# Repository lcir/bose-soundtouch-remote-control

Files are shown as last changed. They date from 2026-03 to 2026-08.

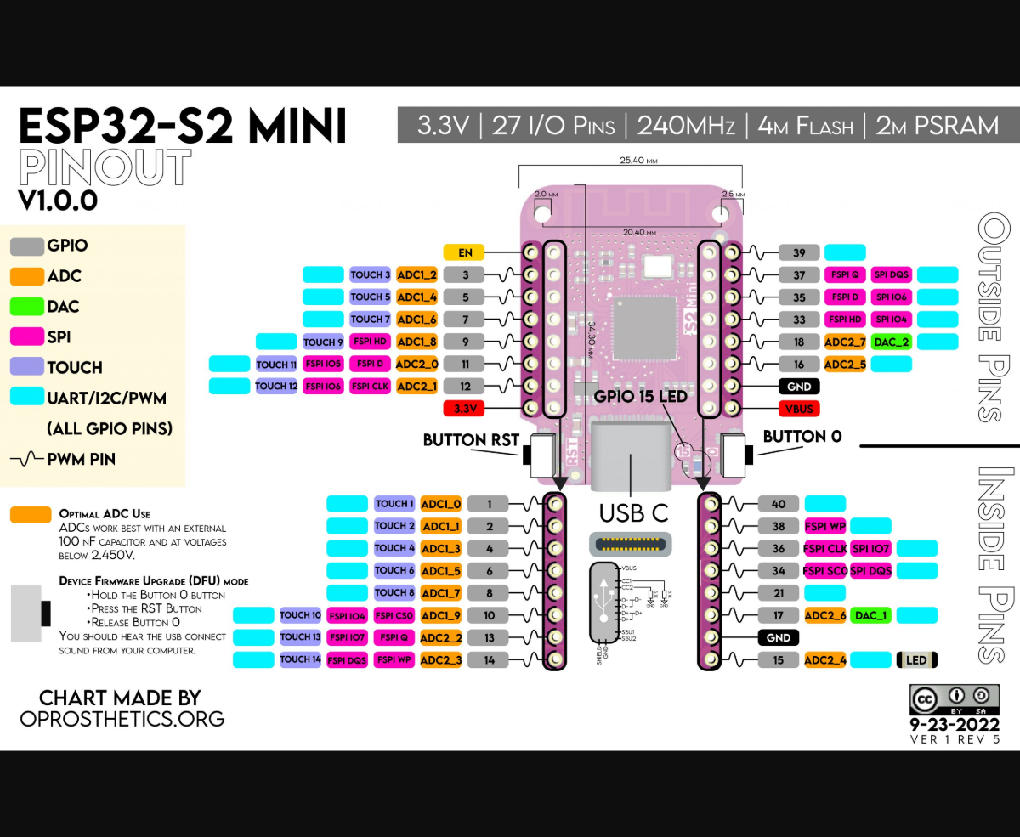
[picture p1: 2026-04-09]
docs/assets/wemos-s2-mini-pinout-base.png

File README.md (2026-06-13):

# Bose SoundTouch SA-5 ESP32 Remote

ESP32 firmware for a dedicated Bose SoundTouch SA-5 wall/desk controller.

Detailed project documentation is in [docs/README.md](/Users/peny/Development/Projects/boser-remote-control/docs/README.md).

Mechanical enclosure CAD is in [cad/bose_remote_enclosure.scad](/Users/peny/Development/Projects/boser-remote-control/cad/bose_remote_enclosure.scad).

The project now defaults to `LOLIN/Wemos S2 Mini` for prototyping.

## Features

- Captive portal setup for Wi-Fi and Bose hostname/IP
- Bose SoundTouch local control over HTTP (`8090`) and WebSocket (`8080`)
- Built-in LAN web UI for phone/browser control
- Rotary encoder volume control with request coalescing
- Encoder push-button driven OLED menu for `Volume`, `Source`, and `Power`
- Single status LED: `on = Bose powered on`, `off = standby/unavailable`
- `128x64` OLED status UI (`SSD1306` over `I2C`)
- Over-the-air (OTA) self-update from GitHub Releases via the web UI

## Default wiring

Current defaults are for `LOLIN/Wemos S2 Mini` and a generic `0.96" 128x64 I2C OLED`.
Change these in `include/PinConfig.h` if your hardware differs.

- `GPIO33` `SDA`
- `GPIO35` `SCL`
- `GPIO7` encoder `A`
- `GPIO9` encoder `B`
- `GPIO11` encoder switch / setup hold button
- `GPIO18` status LED

Buttons are assumed `active low` with `INPUT_PULLUP`.

## Setup flow

1. Flash firmware.
2. On first boot, connect to Wi-Fi `BoseRemote-xxxx`.
3. Open `http://192.168.4.1`.
4. Enter home Wi-Fi credentials and Bose `hostname` or `IP`.
5. Device reboots into normal station mode.

Holding the encoder button during boot for roughly `1.5 s` forces setup mode again.

## Encoder Control

- rotate in idle mode: change volume
- short press: open the OLED menu
- rotate in the menu: choose `Volume`, `Source`, or `Power`
- short press on `Source` or `Power`: open a submenu
- confirm a submenu choice with another short press
- after confirmation, the menu closes and the controller returns to idle volume mode

## LAN Web UI

In normal station mode, the ESP32 also serves a local control page on its own IP address.
Open `http://<esp32-ip>/` in a browser on the same network to:

- change volume
- switch to the next logical source, including `AUX`, `Bluetooth` and grouped `Online`
- directly select the grouped sources exposed by the web UI
- send dynamic `Wake` / `Standby`
- view current Bose state
- check for and apply firmware updates (see below)

## Firmware updates (OTA)

The controller can update its own firmware over the air, pulling the build from
this repo's GitHub Releases — no USB cable needed after the first flash.

How it works:

1. Pushing a `vX.Y.Z` tag triggers the `Build Firmware` workflow, which compiles
   each board and publishes `firmware-<env>.bin` as assets on a GitHub Release.
2. The running firmware embeds its own version (`FIRMWARE_VERSION`, derived from
   the git tag at build time via `scripts/version.py`).
3. In the LAN web UI, the **Firmware** section calls the GitHub API for the
   latest release, compares the tag against the installed version, and offers
   **Update now** when a newer release exists.
4. The device downloads the asset matching its board (`firmware-<env>.bin`),
   flashes it to the inactive OTA slot, and reboots into the new image.

REST endpoints backing this: `GET /api/ota` (status), `POST /api/ota/check`,
`POST /api/ota/apply`.

Cutting a release:

```bash
git tag v0.1.0
git push origin v0.1.0
```

Notes:

- The 4 MB modules use the dual-app `default.csv` partition layout
  (`board_build.partitions`), giving two ~1.25 MB OTA slots. A failed download
  leaves the running image untouched.
- TLS to GitHub uses `setInsecure()` (no certificate pinning) to keep the image
  small; traffic still goes only to `api.github.com` / GitHub's asset CDN and
  only when an update is explicitly requested.

## Build

This repo is prepared for `PlatformIO`.

```bash
pio run
pio run -t upload
pio device monitor
```

The default environment is `lolin_s2_mini`. A compatibility target for generic classic ESP32 boards is still available via:

```bash
pio run -e esp32dev
```

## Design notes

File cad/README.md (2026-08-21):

# CAD návrh krabičky

Parametrický návrh původní svislé krabičky je v [bose_remote_enclosure.scad](/Users/peny/Development/Projects/boser-remote-control/cad/bose_remote_enclosure.scad).

Kompaktní landscape varianta s `OLED` a knobem vedle sebe je v [compact_landscape_enclosure.scad](compact_landscape_enclosure.scad).

## Kompaktní landscape varianta

Nová nízká varianta má vnější rozměry `88 x 34 x 38 mm`:

- `OLED` vlevo
- enkodér / knob vpravo
- bez samostatné stavové `LED`
- `LOLIN/Wemos S2 Mini` uložený naležato v levé spodní kapsě za `OLED`
- S2 Mini se zasouvá zezadu do bočních lišt, `USB-C` míří k zadnímu víku
- kolečko je panelový rotační enkodér: tělo enkodéru je uvnitř, hřídel jde otvorem ven a knob je zvenku
- zadní víko se `USB-C` výřezem, otevřeným spodním slotem pro kabel a ventilačními průřezy

Vygenerované STL díly:

- [compact-landscape-body.stl](compact-landscape-body.stl)
- [compact-landscape-rear-lid.stl](compact-landscape-rear-lid.stl)
- [compact-landscape-panel-layout.stl](compact-landscape-panel-layout.stl)

## Co model obsahuje

- `body`: hlavní díl krabičky s integrovaným čelním panelem, dnem, ložem pro `LOLIN/Wemos S2 Mini`, OLED standoffy a zadním otevřeným servisním prostorem
- `rear_lid`: zadní víko na `4x` šroubek s `USB-C` otvorem a otevřeným slotem pro vedení kabelu
- `panel_layout`: tenký kontrolní výřez rozložení čelního panelu
- `assembly`: vizuální sestava s referenčními bloky pro `OLED`, `S2 Mini`, enkodér a knob

## Výchozí mechanické předpoklady

Model je připravený pro:

- `LOLIN/Wemos S2 Mini`
- běžný `0.96" SSD1306 128x64 I2C OLED` modul
- enkodér s panelovým závitem a zadním modulem podobným `LA132020`

Původní svislý model používá stack `OLED`, enkodér, `LED`.
Kompaktní landscape model používá pouze `OLED` a enkodér vedle sebe.

Pokud se skutečné díly liší, uprav přímo horní parametry v `.scad`.

## Kritické rozměry k přeměření

Před prvním finálním tiskem přeměř:

- `oled_board`, `oled_hole_spacing`, `oled_window`
- `encoder_panel_hole_d` a zadní obrys encoder modulu
- `s2_board`, `usb_opening`, `usb_slot_center_z`

## Export

Pokud máš nainstalovaný `OpenSCAD`, typický export je:

```bash
openscad -D 'part="body"' -o body.stl cad/bose_remote_enclosure.scad
openscad -D 'part="rear_lid"' -o rear-lid.stl cad/bose_remote_enclosure.scad
openscad -D 'part="panel_layout"' -o panel-layout.stl cad/bose_remote_enclosure.scad
```

Export kompaktní landscape varianty:

```bash
openscad -D 'part="body"' -o cad/compact-landscape-body.stl cad/compact_landscape_enclosure.scad
openscad -D 'part="rear_lid"' -o cad/compact-landscape-rear-lid.stl cad/compact_landscape_enclosure.scad
openscad -D 'part="panel_layout"' -o cad/compact-landscape-panel-layout.stl cad/compact_landscape_enclosure.scad
```

## Doporučení pro tisk

- tisknout `body` čelním panelem na podložce; tím vznikne čistý pohledový čelní panel a zadní strana zůstane otevřená pro montáž
- tisknout `rear_lid` plochou stranou na podložce
- pro rychlé ověření rozložení prvků nejdřív vytisknout `panel_layout`
- tryska `0.4 mm`, vrstva `0.2 mm`, `3-4` perimetry
- materiál `PLA` pro rychlý prototyp, `PETG` pro trvalejší kus

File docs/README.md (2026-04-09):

# Dokumentace projektu

Tento adresář obsahuje technickou dokumentaci pro `ESP32` ovladač zesilovače `Bose SoundTouch SA-5`.

English version: [docs/en/README.md](/Users/peny/Development/Projects/boser-remote-control/docs/en/README.md)

## Obsah

- [Přehled projektu](/Users/peny/Development/Projects/boser-remote-control/docs/overview.md)
- [Firmware a provoz](/Users/peny/Development/Projects/boser-remote-control/docs/firmware.md)
- [Zapojení a spojení vodičů](/Users/peny/Development/Projects/boser-remote-control/docs/wiring.md)
- [Bill of Materials](/Users/peny/Development/Projects/boser-remote-control/docs/bom.md)
- [Návrh krabičky](/Users/peny/Development/Projects/boser-remote-control/docs/enclosure.md)

## Rychlá orientace

- `ESP32` komunikuje s `Bose SA-5` pouze přes `Wi‑Fi`.
- Na Bose se nepřipojuje žádný ovládací vodič, relé ani analogový potenciometr.
- Všechny fyzické ovládací prvky jsou připojené jen k `ESP32`.
- `ESP32` posílá do Bose lokální síťové příkazy přes `HTTP` a poslouchá změny přes `WebSocket`.
- V normálním režimu `ESP32` zároveň poskytuje lokální webové ovládání v LAN.
- Web aktuálně nabízí dynamické `Wake/Standby` a seskupené zdroje `AUX`, `Bluetooth`, `Online`.
- [wiring.md](/Users/peny/Development/Projects/boser-remote-control/docs/wiring.md) nově obsahuje i obrazek s projektovym pinoutem `LOLIN/Wemos S2 Mini` a napojenymi komponentami.

## Soubory v projektu

- Hlavní firmware: [main.cpp](/Users/peny/Development/Projects/boser-remote-control/src/main.cpp)
- Bose komunikace: [BoseClient.cpp](/Users/peny/Development/Projects/boser-remote-control/src/BoseClient.cpp)
- Setup portal: [CaptivePortal.cpp](/Users/peny/Development/Projects/boser-remote-control/src/CaptivePortal.cpp)
- LAN web UI: [ControlWebServer.cpp](/Users/peny/Development/Projects/boser-remote-control/src/ControlWebServer.cpp)
- Vstupy: [InputController.cpp](/Users/peny/Development/Projects/boser-remote-control/src/InputController.cpp)
- OLED UI: [UiRenderer.cpp](/Users/peny/Development/Projects/boser-remote-control/src/UiRenderer.cpp)
- Piny: [PinConfig.h](/Users/peny/Development/Projects/boser-remote-control/include/PinConfig.h)

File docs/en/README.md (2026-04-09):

# Project Documentation

This directory contains the English technical documentation for the `ESP32` controller for the `Bose SoundTouch SA-5` amplifier.

## Contents

- [Project Overview](/Users/peny/Development/Projects/boser-remote-control/docs/en/overview.md)
- [Firmware and Operation](/Users/peny/Development/Projects/boser-remote-control/docs/en/firmware.md)
- [Wiring and Connections](/Users/peny/Development/Projects/boser-remote-control/docs/en/wiring.md)
- [Bill of Materials](/Users/peny/Development/Projects/boser-remote-control/docs/en/bom.md)

## Quick Orientation

- The `ESP32` communicates with the `Bose SA-5` only over `Wi-Fi`.
- There is no control wire, relay, or analog potentiometer connected to Bose.
- All physical controls are connected only to the `ESP32`.
- The `ESP32` sends local network commands to Bose over `HTTP` and listens for changes over `WebSocket`.
- In normal mode the `ESP32` also provides a local web control UI on the LAN.
- [wiring.md](/Users/peny/Development/Projects/boser-remote-control/docs/en/wiring.md) now also includes a project pinout diagram for `LOLIN/Wemos S2 Mini` with connected components.

## Project Files

- Main firmware: [main.cpp](/Users/peny/Development/Projects/boser-remote-control/src/main.cpp)
- Bose communication: [BoseClient.cpp](/Users/peny/Development/Projects/boser-remote-control/src/BoseClient.cpp)
- Setup portal: [CaptivePortal.cpp](/Users/peny/Development/Projects/boser-remote-control/src/CaptivePortal.cpp)
- LAN web UI: [ControlWebServer.cpp](/Users/peny/Development/Projects/boser-remote-control/src/ControlWebServer.cpp)
- Inputs: [InputController.cpp](/Users/peny/Development/Projects/boser-remote-control/src/InputController.cpp)
- OLED UI: [UiRenderer.cpp](/Users/peny/Development/Projects/boser-remote-control/src/UiRenderer.cpp)
- Pins: [PinConfig.h](/Users/peny/Development/Projects/boser-remote-control/include/PinConfig.h)

## Notes

- The original Czech documentation remains available in the parent `docs/` directory.
- The enclosure document linked from the Czech index is not currently present in the repository, so it is not mirrored here.

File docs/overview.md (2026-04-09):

# Přehled projektu

## Cíl

Cílem projektu je postavit samostatný fyzický ovladač pro `Bose SoundTouch SA-5`, který bude fungovat bez telefonu a bez závislosti na cloudových službách Bose. Ovladač je založený na `ESP32` a ovládá zesilovač přes lokální `Wi‑Fi` síť.

## Co zařízení umí

- nastavení domácí `Wi‑Fi` a `Bose` hostu přes captive portal
- zobrazení základního stavu na `OLED 128x64`
- změnu hlasitosti rotačním enkodérem
- ovládání `Volume`, `Source` a `Power` přes menu na tlačítku encoderu
- indikaci stavu přes jednu stavovou LED
- čtení aktuální hlasitosti, zdroje a `now playing`
- reakci na změny stavu z Bose přes `WebSocket`
- lokální webové ovládání z telefonu nebo notebooku v téže `Wi‑Fi`
- webové tlačítko `Wake/Standby` podle aktuálního stavu Bose
- webový seznam zdrojů seskupený do přehledných voleb `AUX`, `Bluetooth` a `Online`

## Architektura

Systém je rozdělený na pět hlavních částí:

- `InputController`
  - čte stav enkodéru a tlačítka encoderu
  - dělá debounce stisku
- `BoseClient`
  - odesílá `HTTP` příkazy na Bose
  - čte `/sources`, `/volume`, `/now_playing`
  - drží `WebSocket` spojení a vyvolává refresh stavů
- `CaptivePortal`
  - při prvním startu vytvoří `AP`
  - přes web uloží `SSID`, heslo a `Bose host/IP`
- `ControlWebServer`
  - v normálním režimu poskytuje LAN web UI
  - zobrazuje stav a volá stejné akce jako fyzické ovládání
  - seskupuje syrové Bose zdroje do jednoduššího webového modelu
- `UiRenderer`
  - vykresluje normální provozní obrazovku
  - vykresluje setup režim

## Provozní režimy

### 1. Setup režim

Použije se při prvním startu nebo po servisním podržení tlačítka encoderu při bootu. `ESP32` vytvoří vlastní `AP` a čeká na uložení konfigurace.

### 2. Normální režim

`ESP32` se připojí do domácí sítě, naváže spojení s `Bose SA-5`, průběžně aktualizuje stav na displeji a současně vystaví jednoduché webové ovládání v lokální síti.

## Tok událostí

1. Uživatel otočí enkodérem, klikne encoder nebo použije lokální web.
2. `ESP32` převede akci na síťový příkaz Bose.
3. Bose vrátí stav přes `HTTP` nebo pošle změnu přes `WebSocket`.
4. `ESP32` načte aktuální data a překreslí displej.

## Omezení `v1`

- pouze jedno cílové `Bose` zařízení
- bez automatického vyhledávání v síti
- bez cloudových presetů a procházení hudebních služeb
- bez fyzického odpojování napájení zesilovače

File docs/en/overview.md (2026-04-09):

# Project Overview

## Goal

The goal of this project is to build a standalone physical controller for the `Bose SoundTouch SA-5` that works without a phone and without depending on Bose cloud services. The controller is based on an `ESP32` and controls the amplifier over the local `Wi-Fi` network.

## Device Features

- home `Wi-Fi` and `Bose` host setup through a captive portal
- basic status display on a `128x64 OLED`
- volume control with a rotary encoder
- `Volume`, `Source`, and `Power` control through an encoder-button menu
- status indication with a single status LED
- reading current volume, source, and `now playing`
- reacting to Bose state changes over `WebSocket`
- local web control from a phone or laptop on the same `Wi-Fi`

## Architecture

The system is split into five main parts:

- `InputController`
  - reads the encoder and encoder push switch
  - handles press debounce
- `BoseClient`
  - sends `HTTP` commands to Bose
  - reads `/sources`, `/volume`, `/now_playing`
  - maintains the `WebSocket` connection and triggers state refreshes
- `CaptivePortal`
  - starts an `AP` on first boot
  - stores `SSID`, password, and `Bose host/IP` through the web UI
- `ControlWebServer`
  - provides a LAN web UI in normal mode
  - shows status and calls the same actions as the physical controls
- `UiRenderer`
  - draws the normal operation screen
  - draws the setup mode screen

## Operating Modes

### 1. Setup Mode

Used on first boot or after holding the encoder button during boot. The `ESP32` creates its own `AP` and waits for configuration to be saved.

### 2. Normal Mode

The `ESP32` joins the home network, connects to the `Bose SA-5`, keeps the display updated, and at the same time exposes a simple web control interface on the local network.

## Event Flow

1. The user turns the encoder, clicks the encoder button, or uses the local web UI.
2. The `ESP32` converts the action into a Bose network command.
3. Bose returns state via `HTTP` or pushes a change over `WebSocket`.
4. The `ESP32` fetches the latest data and redraws the display.

## `v1` Limitations

- only one target `Bose` device
- no automatic discovery on the network
- no cloud presets or music service browsing
- no physical power disconnection of the amplifier

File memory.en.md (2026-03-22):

# Project Memory

## Current Baseline

- Project: `ESP32` local controller for `Bose SoundTouch SA-5`
- Goal: physical controller plus local LAN web UI, all over local `Wi-Fi`
- Firmware stack: `C++`, `PlatformIO`, `Arduino`
- Default prototype board: `LOLIN/Wemos S2 Mini`
- Default display: generic `0.96" 128x64 I2C OLED`, assumed `SSD1306` compatible
- Default encoder: LaskaKit `LA132020`, rotary encoder with button and `RC` filter

## Core Functional Decisions

- Bose communication is local only:
  - `HTTP` on port `8090`
  - `WebSocket` on port `8080`
  - subprotocol `gabbo`
- Setup uses captive portal:
  - device AP `BoseRemote-xxxx`
  - config saved in `NVS` via `Preferences`
- Normal runtime has two control surfaces:
  - physical controls on the device
  - local web UI served from the ESP32 in LAN
- Physical control model is now:
  - rotary encoder = volume
  - `Source` button = next selectable source
  - `Standby` button = explicit `standby/off`
  - bi-color LED = `red standby/off`, `green on`
- Standby uses explicit Bose standby behavior, not blind `POWER` toggle
- Web power control uses dynamic `Wake` / `Standby`
- Source rotation now aims to include:
  - local `AUX`
  - `Bluetooth`
  - online/non-local sources exposed by Bose `/sources`
- Web source list is grouped for usability:
  - `AUX IN 1/2/3`
  - `Bluetooth`
  - `Online`
- `QPlay` placeholders are intentionally hidden from the UI

## Current Pinout

- `GPIO33` -> OLED `SDA`
- `GPIO35` -> OLED `SCL`
- `GPIO7` -> encoder `A`
- `GPIO9` -> encoder `B`
- `GPIO5` -> `Source` button
- `GPIO11` -> `Standby` button / setup hold at boot
- `GPIO16` -> LED `Red`
- `GPIO18` -> LED `Green`

## Hardware Assumptions

- Buttons are wired to `GND`
- Firmware uses `INPUT_PULLUP`
- OLED is powered from `3.3V`
- LED logic currently assumes `common cathode` / `active HIGH`
- If LED is `common anode`, change `POWER_LED_ACTIVE_HIGH` in [PinConfig.h](/Users/peny/Development/Projects/boser-remote-control/include/PinConfig.h)
- Add one resistor per LED branch, typically `220R` to `1k`

## Implemented Modules

- [src/BoseClient.cpp](/Users/peny/Development/Projects/boser-remote-control/src/BoseClient.cpp)
  - Bose HTTP/WebSocket communication
  - source refresh, volume refresh, now playing refresh
  - explicit `standby()`
- [src/CaptivePortal.cpp](/Users/peny/Development/Projects/boser-remote-control/src/CaptivePortal.cpp)
  - first-boot and recovery setup portal
- [src/ControlWebServer.cpp](/Users/peny/Development/Projects/boser-remote-control/src/ControlWebServer.cpp)
  - local LAN control page
  - `/api/state`, `/api/power`, `/api/source/next`, `/api/source/select`, `/api/standby`, `/api/volume`
- [src/InputController.cpp](/Users/peny/Development/Projects/boser-remote-control/src/InputController.cpp)
  - button debounce
  - encoder handling
- [src/UiRenderer.cpp](/Users/peny/Development/Projects/boser-remote-control/src/UiRenderer.cpp)
  - OLED status rendering

## Important Runtime Behavior

- Web UI starts only after station `Wi-Fi` is connected
- Web UI stops when `Wi-Fi` disconnects or device enters setup mode
- OLED uses explicit `I2C` config:
  - address `0x3C`
  - bus speed `400 kHz`
- Volume changes are coalesced with short delay before Bose request
- WebSocket updates do not directly mutate state from payload; they trigger refreshes
- If WebSocket is down, app falls back to periodic polling

## Known Unknowns / Unverified

- Build has not been verified locally in this environment because `PlatformIO` is not installed here
- Real hardware behavior on the actual `SA-5` is not yet tested
- OLED controller is assumed compatible with `SSD1306`; if not, `U8g2` display class may need to change
- `standby` endpoint behavior should be confirmed against the real `SA-5`
- Actual source identifiers from `/sources` should be verified on the real amplifier
- Wake via `POWER` key should be confirmed on the real `SA-5`
- Which online sources are exposed as selectable depends on the real `/sources` payload and Bose account state

## Best Next Improvements

- Add a hardware self-test mode:
  - verify OLED
  - blink both LED channels
  - test buttons
  - test encoder direction
- Add serial debug logging with controllable verbosity
- Add lightweight I2C scan mode for display bring-up
- Add web endpoint for configuration/status details if needed
- Add web-based config entry or config edit in normal mode if desired
- Confirm real Bose power-state mapping and source list behavior

## Repo Notes

- This workspace is currently not a git repository
- Main user-facing docs are:
  - [README.md](/Users/peny/Development/Projects/boser-remote-control/README.md)
  - [docs/README.md](/Users/peny/Development/Projects/boser-remote-control/docs/README.md)
  - [plan.md](/Users/peny/Development/Projects/boser-remote-control/plan.md)

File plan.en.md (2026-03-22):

# Plan: Bose SoundTouch SA-5 ESP32 Remote

## Goal

Build a standalone physical controller for the `Bose SoundTouch SA-5` that uses an `ESP32` to control the amplifier over `Wi-Fi`, without needing a phone or the Bose app.

## Chosen Direction

- firmware will be written in `C++`
- build and project management will use `PlatformIO`
- the framework will be `Arduino` for `ESP32`
- the default prototype board will be `LOLIN/Wemos S2 Mini`
- the device will control one specific `Bose SoundTouch SA-5`
- Bose will be connected only over local `Wi-Fi`

## Hardware v1

- `LOLIN/Wemos S2 Mini`
- `OLED SSD1306 128x64` over `I2C`
- LaskaKit rotary encoder with button and `RC` filter (`LA132020`) for the first prototype
- `Source` button
- `Standby` button
- two-color `red/green` LED for status indication

## Controls

- the encoder changes volume
- volume changes are coalesced and sent after a short delay
- `Source` switches to the next logical source
- the physical `Standby` button powers the `SoundTouch` down
- device state is shown on the two-color LED
- the same basic controls are also available through the local web UI
- the web UI has a dynamic `Wake/Standby` button
- the web UI groups sources into clear items:
  - `AUX IN 1`
  - `AUX IN 2`
  - `AUX IN 3`
  - `Bluetooth`
  - `Online`

## UI

The `OLED` display should show:

- `Wi-Fi` status
- `WebSocket` connection status
- current source
- volume
- `mute` status
- short `artist/track` text when available

When source or volume changes, a highlighted overlay is shown briefly.

LED logic:

- `red`: `standby/off`
- `green`: `on`

## Setup Flow

- on first start or when configuration is missing, the device enters setup mode
- the `ESP32` creates its own `AP`
- the user connects to the captive portal
- `Wi-Fi SSID`, password, and `Bose host/IP` are saved
- configuration is stored in `NVS`
- holding the `Standby` button during boot returns the device to setup mode
- in normal mode the `ESP32` exposes a simple control web UI on the LAN

## Bose Communication

Use the local `SoundTouch` API:

- `HTTP` on port `8090`
- `WebSocket` on port `8080`
- subprotocol `gabbo`

Used endpoints:

- `/info`
- `/sources`
- `/volume`
- `/now_playing`
- `/select`
- `/key`

Rules:

- load sources dynamically from `/sources`
- the user-facing UI groups raw Bose sources into logical choices
- hide `QPlay` and technical placeholders in the UI
- `Bluetooth` and `Online` may remain selectable even outside `READY` state when that makes sense according to Bose sources
- do not parse websocket changes directly into state, but trigger refresh through `HTTP`
- when the websocket fails, switch to polling mode
- use explicit `standby/off` for power-down, not a blind `POWER` toggle
- for wake, try `POWER` and fall back to selecting a suitable source if needed
- the local web UI should use the same internal actions as the physical controls

## Electrical Wiring v1

- `GPIO33` -> OLED `SDA`
- `GPIO35` -> OLED `SCL`
- `GPIO7` -> encoder `A`
- `GPIO9` -> encoder `B`
- `GPIO5` -> `Source` button
- `GPIO11` -> `Standby` button
- `GPIO16` -> LED `Red`
- `GPIO18` -> LED `Green`

Assumptions:

- buttons are wired to `GND`
- firmware uses `INPUT_PULLUP`
- the `OLED` is powered from `3.3 V`
- Bose is not connected by wire, only over `Wi-Fi`

## v1 Limitations

- no automatic Bose device discovery on the network
- no Bose cloud presets or services
- no physical power disconnection of the amplifier
- no modification of the `SA-5` electronics

## Current Implementation State

The repository already contains an initial implementation:

- `PlatformIO` project
- captive portal
- local control web UI
- web `Wake/Standby`
- grouped `AUX/Bluetooth/Online` sources
- Bose `HTTP` and `WebSocket` client
- OLED renderer
- input layer for encoder and buttons
- basic documentation in `docs/`

## Next Practical Steps

1. Verify the build on `LOLIN/Wemos S2 Mini` using `PlatformIO`.
2. Verify real endpoints and behavior with a real `Bose SA-5`.
3. Remap pins according to the final hardware.
4. Verify encoder direction and button debounce.
5. Test setup flow, reconnect behavior, and `Wi-Fi` outage handling.
6. Optionally add a visual wiring diagram and an exact front-panel design.

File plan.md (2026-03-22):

# Plan: Bose SoundTouch SA-5 ESP32 Remote

## Cíl

Postavit samostatný fyzický ovladač pro `Bose SoundTouch SA-5`, který bude přes `ESP32` ovládat zesilovač po `Wi‑Fi` bez nutnosti používat telefon nebo Bose aplikaci.

## Zvolený směr

- firmware bude v `C++`
- build a správa projektu budou přes `PlatformIO`
- framework bude `Arduino` pro `ESP32`
- výchozí prototypovací deska bude `LOLIN/Wemos S2 Mini`
- zařízení bude ovládat jedno konkrétní `Bose SoundTouch SA-5`
- Bose bude připojené pouze přes lokální `Wi‑Fi`

## Hardware v1

- `LOLIN/Wemos S2 Mini`
- `OLED SSD1306 128x64` přes `I2C`
- LaskaKit rotační enkodér s tlačítkem a `RC` filtrem (`LA132020`) pro první prototyp
- tlačítko `Source`
- tlačítko `Standby`
- dvoubarevná LED `red/green` pro indikaci stavu

## Ovládání

- enkodér mění hlasitost
- změny hlasitosti se coalescují a odesílají po krátké prodlevě
- `Source` přepíná na další logický zdroj
- fyzické `Standby` tlačítko vypíná `SoundTouch`
- stav zařízení se zobrazuje na dvoubarevné LED
- stejné základní ovládání je dostupné i přes lokální web
- web má dynamické tlačítko `Wake/Standby`
- web seskupuje zdroje do přehledných položek:
  - `AUX IN 1`
  - `AUX IN 2`
  - `AUX IN 3`
  - `Bluetooth`
  - `Online`

## UI

Na `OLED` displeji se má zobrazovat:

- stav `Wi‑Fi`
- stav `WebSocket` spojení
- aktuální zdroj
- hlasitost
- stav `mute`
- krátký text `artist/track`, pokud je dostupný

Při změně zdroje nebo hlasitosti se krátce zobrazí zvýrazněný overlay.

LED logika:

- `červená`: `standby/off`
- `zelená`: `on`

## Setup flow

- při prvním startu nebo chybějící konfiguraci přejde zařízení do setup režimu
- `ESP32` vytvoří vlastní `AP`
- uživatel se připojí na captive portal
- uloží se `Wi‑Fi SSID`, heslo a `Bose host/IP`
- konfigurace se uloží do `NVS`
- podržení `Standby` tlačítka při bootu vrátí zařízení do setup režimu
- v normálním režimu bude `ESP32` vystavovat jednoduchý ovládací web v LAN

## Bose komunikace

Použít lokální `SoundTouch` API:

- `HTTP` na portu `8090`
- `WebSocket` na portu `8080`
- subprotocol `gabbo`

Použité endpointy:

- `/info`
- `/sources`
- `/volume`
- `/now_playing`
- `/select`
- `/key`

Pravidla:

- zdroje načítat dynamicky z `/sources`
- uživatelské UI seskupuje syrové Bose zdroje do logických voleb
- `QPlay` a technické placeholdery v UI skrýt
- `Bluetooth` i `Online` mohou být volitelné i mimo stav `READY`, pokud to dává smysl podle Bose zdrojů
- změny z websocketu neparsovat přímo do stavu, ale vyvolat refresh přes `HTTP`
- při pádu websocketu přejít do poll režimu
- pro vypnutí použít explicitní `standby/off`, ne `POWER` toggle
- pro probuzení zkusit `POWER` a při potřebě fallback přes výběr vhodného zdroje
- lokální web bude používat stejné interní akce jako fyzické ovládání

## Elektrické zapojení v1

- `GPIO33` -> OLED `SDA`
- `GPIO35` -> OLED `SCL`
- `GPIO7` -> encoder `A`
- `GPIO9` -> encoder `B`
- `GPIO5` -> tlačítko `Source`
- `GPIO11` -> tlačítko `Standby`
- `GPIO16` -> LED `Red`
- `GPIO18` -> LED `Green`

Předpoklady:

- tlačítka jsou zapojená proti `GND`
- firmware používá `INPUT_PULLUP`
- `OLED` je napájený z `3.3 V`
- Bose není propojený vodičem, pouze přes `Wi‑Fi`

## Omezení v1

- bez automatického discovery Bose zařízení v síti
- bez cloudových presetů a služeb Bose
- bez fyzického vypínání napájení zesilovače
- bez zásahu do elektroniky `SA-5`

## Aktuální stav implementace

V repozitáři je připravená první implementace:

- `PlatformIO` projekt
- captive portal
- lokální ovládací web
- webové `Wake/Standby`
- seskupené zdroje `AUX/Bluetooth/Online`
- Bose `HTTP` a `WebSocket` klient
- OLED renderer
- input vrstva pro enkodér a tlačítka
- základní dokumentace v `docs/`

## Další praktické kroky

1. Ověřit build na `LOLIN/Wemos S2 Mini` přes `PlatformIO`.
2. Ověřit skutečné endpointy a chování s reálným `Bose SA-5`.
3. Přemapovat piny podle finálního hardware.
4. Ověřit směr enkodéru a debounce tlačítek.
5. Otestovat setup flow, reconnect a chování při výpadku `Wi‑Fi`.
6. Případně doplnit obrázkové schéma zapojení a přesný návrh čelního panelu.

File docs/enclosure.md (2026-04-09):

# Návrh krabičky

Mechanický návrh je uložený v [cad/bose_remote_enclosure.scad](/Users/peny/Development/Projects/boser-remote-control/cad/bose_remote_enclosure.scad).

## Koncepce

Aktuální verze používá dva hlavní tisknutelné díly:

- `body`: hlavní díl s integrovaným čelním panelem a dnem
- `rear_lid`: servisní zadní víko

Ovládací prvky jsou na skutečně předním panelu:

- `OLED` nahoře uprostřed
- enkodér uprostřed
- jemně zapuštěná stavová `LED` dole uprostřed

`LOLIN/Wemos S2 Mini` je uložená vzadu na lištách a zadní víko má nejen průchod pro `USB-C` konektor, ale i otevřený slot směrem dolů, aby šel kabel vést ven i při zavřeném víku.

## Výchozí rozměry

| Parametr | Hodnota |
|---|---:|
| šířka krabičky | `92 mm` |
| hloubka krabičky | `76 mm` |
| výška krabičky | `54 mm` |
| tloušťka stěny | `2.4 mm` |
| čelní panel | `3.0 mm` |
| spodní stěna | `2.8 mm` |
| zadní víko | `3.0 mm` |

## Rozložení čelního panelu

Souřadnice jsou měřené od levého dolního rohu čelního panelu.

| Prvek | Střed X | Střed Y | Otvor / okno |
|---|---:|---:|---|
| `OLED` okno | `46.0 mm` | `39.0 mm` | `24 x 13 mm` |
| Enkodér | `46.0 mm` | `22.0 mm` | `7.4 mm` |
| `LED` | `46.0 mm` | `8.5 mm` | `2.2 mm` |

## Kontrolní náčrt

```text
Pohled zepředu

  +--------------------------------------------+
  |              [ OLED 24 x 13 ]              |
  |                                            |
  |                   (ENC)                    |
  |                                            |
  |                    o LED                   |
  +--------------------------------------------+
```

## Montážní logika

Montáž je nyní řešená tak, aby šly díly opravdu osadit:

1. vytisknout `body` čelním panelem na podložce
2. zezadu osadit `OLED`, enkodér a LED do integrovaného čelního panelu
3. zavést vodiče dovnitř těla
4. zasunout `LOLIN/Wemos S2 Mini` do zadních lišt
5. zapojit `USB-C`
6. zavřít `rear_lid`

## Co zkontrolovat na reálných dílech

- `OLED` modul musí sedět na rozteč standoffů `23.2 x 23.2 mm`
- vzdálenost `OLED` PCB od panelu musí odpovídat `oled_backoff_from_panel`
- encoder modul musí mít stále dost místa za panelem v oblasti `encoder_relief_d`
- LED pouzdro musí sedět do otvoru `2.2 mm` a do zadního zapuštění `6.8 mm`
- `USB-C` konektor `S2 Mini` musí sedět do výřezu `13.0 x 8.0 mm`
- průměr a výška kabelového límce musí projít spodním slotem zadního víka

## Ověření po prvním tisku

- `OLED` jde přišroubovat zezadu do integrovaného čelního panelu
- prsty mají dost místa kolem enkodéru
- LED je viditelná, ale nepůsobí příliš dominantně proti displeji
- `USB-C` jde zasunout a kabel projde zadním slotem bez páčení desky

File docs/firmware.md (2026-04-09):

# Firmware a provoz

## Vývojové prostředí

Projekt je připravený pro `PlatformIO` s `Arduino` frameworkem.

- konfigurace build prostředí: [platformio.ini](/Users/peny/Development/Projects/boser-remote-control/platformio.ini)
- hlavní vstup firmware: [main.cpp](/Users/peny/Development/Projects/boser-remote-control/src/main.cpp)
- výchozí build target: `lolin_s2_mini`

## Použité knihovny

- `U8g2` pro `SSD1306 OLED`
- `WebSockets` pro Bose notifikace
- `ESP32Encoder` pro rotační enkodér
- `Preferences` pro perzistentní konfiguraci
- `WiFi`, `WebServer`, `DNSServer`, `HTTPClient`

## Build a flash

```bash
cd /Users/peny/Development/Projects/boser-remote-control
pio run
pio run -t upload
pio device monitor
```

Pokud `pio` není v `PATH`, lze použít:

```bash
~/.local/bin/pio run
~/.local/bin/pio run -t upload
~/.local/bin/pio device monitor
```

Pro kompatibilní klasický `ESP32` target je v projektu stále i alternativní environment:

```bash
pio run -e esp32dev
```

Poznámka pro `LOLIN/Wemos S2 Mini`:

- build zapíná `USB CDC on boot`
- `Serial` tedy běží přes nativní `USB`, ne přes externí `USB-UART`

## Konfigurace

Konfigurace se ukládá do `NVS` přes `Preferences`.

Ukládané položky:

- `wifi_ssid`
- `wifi_pwd`
- `bose_host`
- `http_port`
- `ws_port`
- `display_flip`

Datový model je definovaný v [Types.h](/Users/peny/Development/Projects/boser-remote-control/include/Types.h) a ukládání v [ConfigStore.cpp](/Users/peny/Development/Projects/boser-remote-control/src/ConfigStore.cpp).

## Setup flow

1. Po prvním bootu se spustí `AP` `BoseRemote-xxxx`.
2. Uživatel se připojí telefonem nebo notebookem.
3. Otevře `http://192.168.4.1`.
4. Zadá domácí `Wi‑Fi` a `Bose host/IP`.
5. `ESP32` uloží konfiguraci a přepne se do normálního režimu.

Servisní návrat do setup režimu:

- při startu podržet tlačítko encoderu přibližně `1.5 s`

## Web rozhraní

Firmware používá dva web režimy:

- `CaptivePortal`
  - aktivní pouze v setup režimu
  - běží na `192.168.4.1`
  - slouží jen pro uložení `Wi‑Fi` a `Bose host/IP`
- `ControlWebServer`
  - aktivní v normálním režimu
  - běží na IP adrese přidělené v domácí síti
  - poskytuje jednoduché mobilní ovládání a stavový přehled

Endpointy lokálního ovládacího webu:

- `GET /`
- `GET /api/state`
- `POST /api/power`
- `POST /api/source/next`
- `POST /api/source/select`
- `POST /api/standby`
- `POST /api/volume`

## Bose komunikace

### HTTP

Použité endpointy:

- `/info`
- `/sources`
- `/volume`
- `/now_playing`
- `/select`
- `/key`

### WebSocket

- host: stejný jako `Bose host`
- port: `8080`
- path: `/`
- subprotocol: `gabbo`

Při přijetí notifikací `volumeUpdated`, `sourcesUpdated`, `nowPlayingUpdated` firmware nenačítá stav z payloadu přímo, ale provede nový `HTTP` refresh.

## Logika ovládání

### Enkodér

- každý krok mění cílovou hlasitost o `1`
- odeslání na Bose je zpožděné o `100 ms`
- rychlé otáčení tedy nevytváří desítky bezprostředních requestů
- krátký stisk otevře menu na OLED
- menu má položky `Volume`, `Source`, `Power`
- po potvrzení submenu se menu zavře a ovládání se vrátí na hlasitost
- při neaktivitě se menu po několika sekundách samo zavře

### Tlačítko encoderu

- používá se pro otevření menu a potvrzení volby
- při bootu slouží i jako servisní hold pro návrat do setup režimu

### Web UI

- web volá stejnou Bose logiku jako fyzická tlačítka
- stránka pravidelně načítá stav přes `/api/state`
- hlasitost se odesílá přes krátce zpožděné `POST /api/volume`
- hlavní power tlačítko se přepíná mezi `Wake` a `Standby`
- barva power tlačítka sleduje stav:
  - `red` pro probuzení ze standby
  - `green` pro uspání
- wake se snaží zařízení probudit přes `POWER` key a v případě potřeby použije fallback přes výběr vhodného zdroje
- rotace zdrojů i webový seznam zahrnují vedle `AUX` i `Bluetooth` a jednu seskupenou položku `Online`
- syrové položky jako `QPlay` nebo technické placeholdery se ve webovém UI nezobrazují

### Stavová LED

- LED svítí, když je Bose zapnutý a dostupný
- LED je zhasnutá, když je Bose ve `standby/off` stavu nebo není dostupný

### Displej

Normální obrazovka ukazuje:

- stav `Wi‑Fi`
- stav `WebSocket`
- aktivní zdroj
- hlasitost a `mute`
- krátký řádek `artist/track`

Menu obrazovka ukazuje:

- název menu nebo submenu
- zvýrazněnou aktuální položku
- stručnou nápovědu nebo stavovou hlášku na spodním řádku

## Chování při chybách

- při výpadku `Wi‑Fi` se zařízení pokouší znovu připojit
- při výpadku `WebSocket` přechází do poll režimu po `5 s`
- při obnovení připojení se znovu otevírá Bose session a načítá aktuální stav

## Co bude pravděpodobně potřeba doladit na reálném hardware

- směr enkodéru
- konkrétní piny podle použité desky
- orientace OLED
- mechanické umístění encoderu a jeho tlačítka
- latence a případný krok hlasitosti

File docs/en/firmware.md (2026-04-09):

# Firmware and Operation

## Development Environment

The project is prepared for `PlatformIO` with the `Arduino` framework.

- build configuration: [platformio.ini](/Users/peny/Development/Projects/boser-remote-control/platformio.ini)
- main firmware entry point: [main.cpp](/Users/peny/Development/Projects/boser-remote-control/src/main.cpp)
- default build target: `lolin_s2_mini`

## Libraries Used

- `U8g2` for the `SSD1306 OLED`
- `WebSockets` for Bose notifications
- `ESP32Encoder` for the rotary encoder
- `Preferences` for persistent configuration
- `WiFi`, `WebServer`, `DNSServer`, `HTTPClient`

## Build and Flash

```bash
cd /Users/peny/Development/Projects/boser-remote-control
pio run
pio run -t upload
pio device monitor
```

If `pio` is not in `PATH`, you can use:

```bash
~/.local/bin/pio run
~/.local/bin/pio run -t upload
~/.local/bin/pio device monitor
```

An alternative environment for a compatible classic `ESP32` target is still present in the project:

```bash
pio run -e esp32dev
```

Note for `LOLIN/Wemos S2 Mini`:

- the build enables `USB CDC on boot`
- `Serial` therefore runs over native `USB`, not an external `USB-UART`

## Configuration

Configuration is stored in `NVS` using `Preferences`.

Stored items:

- `wifi_ssid`
- `wifi_pwd`
- `bose_host`
- `http_port`
- `ws_port`
- `display_flip`

The data model is defined in [Types.h](/Users/peny/Development/Projects/boser-remote-control/include/Types.h) and persistence is implemented in [ConfigStore.cpp](/Users/peny/Development/Projects/boser-remote-control/src/ConfigStore.cpp).

## Setup Flow

1. On first boot the `BoseRemote-xxxx` `AP` starts.
2. The user connects using a phone or laptop.
3. They open `http://192.168.4.1`.
4. They enter home `Wi-Fi` and `Bose host/IP`.
5. The `ESP32` stores the configuration and switches to normal mode.

Service return to setup mode:

- hold the encoder button during startup for roughly `1.5 s`

## Web Interface

The firmware uses two web modes:

- `CaptivePortal`
  - active only in setup mode
  - runs on `192.168.4.1`
  - used only to store `Wi-Fi` and `Bose host/IP`
- `ControlWebServer`
  - active in normal mode
  - runs on the IP address assigned on the home network
  - provides simple mobile control and a status overview

Local control web endpoints:

- `GET /`
- `GET /api/state`
- `POST /api/power`
- `POST /api/source/next`
- `POST /api/source/select`
- `POST /api/standby`
- `POST /api/volume`

## Bose Communication

### HTTP

Used endpoints:

- `/info`
- `/sources`
- `/volume`
- `/now_playing`
- `/select`
- `/key`

### WebSocket

- host: same as `Bose host`
- port: `8080`
- path: `/`
- subprotocol: `gabbo`

When notifications such as `volumeUpdated`, `sourcesUpdated`, or `nowPlayingUpdated` are received, the firmware does not read the state directly from the payload. It performs a fresh `HTTP` refresh instead.

## Control Logic

### Encoder

- every step changes the target volume by `1`
- sending to Bose is delayed by `100 ms`
- fast rotation therefore does not create dozens of immediate requests
- a short press opens the OLED menu
- the menu contains `Volume`, `Source`, and `Power`
- confirming a submenu choice closes the menu and returns control to idle volume mode
- the menu closes automatically after a few seconds of inactivity

### Encoder Button

- opens the menu and confirms selections
- also serves as the boot-time service hold for returning to setup mode

### Web UI

- the web UI calls the same Bose logic as the physical controls
- the page periodically fetches state through `/api/state`
- volume is sent through a slightly delayed `POST /api/volume`
- the main power button toggles between `Wake` and `Standby`
- the power button color follows the state:
  - `green` for waking from standby
  - `red` for putting the device into standby
- source rotation and the web list include `AUX`, `Bluetooth`, and suitable online sources if Bose exposes them through `/sources`

### Status LED

- the LED is on when Bose is powered on and available
- the LED is off when Bose is in `standby/off` state or unavailable

### Display

The normal screen shows:

- `Wi-Fi` status
- `WebSocket` status
- current source
- volume and `mute`
- a short `artist/track` line

The menu screen shows:

- the menu or submenu title
- the currently highlighted item
- a short hint or status line at the bottom

## Error Handling

- when `Wi-Fi` drops, the device tries to reconnect
- when `WebSocket` drops, it switches to polling mode after `5 s`
- when connectivity returns, it reopens the Bose session and reloads current state

## Things Likely To Need Tuning On Real Hardware

- encoder direction
- exact pins for the board in use
- OLED orientation
- physical placement of the encoder and its push button
- latency and possible volume step tuning

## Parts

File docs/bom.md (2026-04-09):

# Bill of Materials

Tento kusovník je připravený pro aktuální ovladač `Bose SoundTouch SA-5` s `ESP32`, `OLED`, rotačním enkodérem s tlačítkem a jednou stavovou LED.

## Varianta A: rychlý prototyp na stole

| Položka | Qty | Doporučený typ | Poznámka |
|---|---:|---|---|
| `ESP32` vývojová deska | 1 | `LOLIN/Wemos S2 Mini` | Výchozí deska pro první prototyp |
| OLED displej | 1 | `SSD1306 0.96" 128x64 I2C` | 4 vodiče, jednoduché zapojení |
| Rotační enkodér | 1 | LaskaKit `Rotační encoder s tlačítkem a RC s filtrem`, `LA132020` | Výchozí volba pro první prototyp |
| Knoflík na enkodér | 1 | pro hřídel dle zvoleného enkodéru | Typicky `6 mm` |
| Stavová LED | 1 | běžná jednobarevná LED | Svítí jen při stavu `on` |
| Rezistor pro LED | 1 | `220R` až `1k` | Sériově k LED |
| Breadboard | 1 | half-size nebo podobný | Na první oživení |
| Jumper vodiče | 1 sada | `Dupont` / breadboard wires | Male-female nebo male-male podle desky |
| USB kabel | 1 | podle desky, pro `LOLIN/Wemos S2 Mini` typicky `USB-C` | Napájení a flash |
| `5 V USB` napájení | 1 | běžný USB adaptér | Pro prototyp stačí telefonní nabíječka |

## Varianta B: čistší vestavba do krabičky

| Položka | Qty | Doporučený typ | Poznámka |
|---|---:|---|---|
| `ESP32` vývojová deska | 1 | stejná jako u prototypu | Může zůstat i ve finální verzi |
| OLED displej | 1 | `SSD1306 0.96" 128x64 I2C` | V panelu vyříznout okno |
| Rotační enkodér | 1 | `Bourns PEC11R` | Lepší mechanická jistota |
| Knoflík na enkodér | 1 | panelový knob | Volit dle estetiky a hřídele |
| Stavová LED | 1 | jednobarevná | Pro indikaci `on` |
| Rezistor pro LED | 1 | `220R` až `1k` | Sériově k LED |
| Prototypovací PCB | 1 | `Perma-Proto` nebo univerzální děrovaný spoj | Na trvalejší propojení |
| Krabička | 1 | plastová `ABS` krabička | Pro panel a mechanickou ochranu |
| Sloupky / distančníky | 4 | `M2.5` nebo `M3` | Dle otvorů displeje a desky |
| Šroubky a matice | sada | `M2.5/M3` | Montáž do krabičky |
| Vodič 24 až 26 AWG | 1 sada | lankový nebo pevný | Pro vnitřní propoje |
| Konektory / pin headery | dle potřeby | `2.54 mm` | Usnadní servis a výměny |
| `5 V USB` zdroj | 1 | trvale připojený adaptér | Napájení finální jednotky |

## Doporučené konkrétní díly

### `ESP32`

- preferovaný typ pro aktuální prototyp: `LOLIN/Wemos S2 Mini`
- alternativa: jiná kvalitní `ESP32` nebo `ESP32-S2` dev deska s `3.3 V` logikou a vyvedenými GPIO

Poznámka:

- aktuální firmware je přizpůsobený na `LOLIN/Wemos S2 Mini`
- výchozí build target v `PlatformIO` je `lolin_s2_mini`

### OLED

- doporučený modul: `SSD1306 128x64`, `0.96"`, `I2C`
- preferovat modul, který spolehlivě funguje na `3.3 V`

### Enkodér

- pro prototyp: LaskaKit `Rotační encoder s tlačítkem a RC s filtrem`, `LA132020`
- parametry prototypové varianty: `20 pulzů na otáčku`, integrované tlačítko, RC filtr proti rušení
- pro finálnější mechaniku: `Bourns PEC11R`
- důvod: RC filtrovaný modul je vhodný pro rychlé oživení na `ESP32`, `Bourns` je mechanicky lepší pro hotové zařízení

### Stavová LED

- doporučená varianta: jednobarevná LED, typicky zelená
- svítí jen při zapnutém a dostupném Bose

## Orientační rozdělení na povinné a volitelné položky

### Povinné pro funkční prototyp

- `ESP32`
- `OLED`
- enkodér
- enkodér s tlačítkem
- stavová LED
- 1 LED rezistor
- vodiče
- napájení

### Volitelné, ale doporučené

- prototypovací PCB
- panel mount tlačítka
- knob na enkodér
- krabička
- distanční sloupky

## Piny a návaznost na BOM

Výchozí pinout firmware:

- `GPIO33` -> `OLED SDA`
- `GPIO35` -> `OLED SCL`
- `GPIO7` -> `Encoder A`
- `GPIO9` -> `Encoder B`
- `GPIO11` -> `Encoder SW`
- `GPIO18` -> `Status LED`

Detail zapojení je v [wiring.md](/Users/peny/Development/Projects/boser-remote-control/docs/wiring.md).

## Doporučení k nákupu

- pro první prototyp nekupovat custom PCB
- začít na existující `LOLIN/Wemos S2 Mini`, kterou už máš
- pokud si nejsi jistý mechanikou, vzít levnější generické tlačítka pro prototyp a kvalitnější panelové díly až do finální krabičky
- pokud bude zařízení v kovové skříni, počítat s horším `Wi‑Fi` a případně upravit polohu `ESP32`

## Referenční díly a orientační ceny

Níže jsou příklady aktuálně dohledatelných dílů, které odpovídají tomuto návrhu. Ceny jsou jen orientační a mohou se lišit podle distributora, DPH a dopravy.

| Položka | Příklad | Orientačně |
|---|---|---:|
| OLED `128x64 I2C` | `Adafruit 0.96" SSD1306`, Product ID `326` | `USD 17.50` |
| Prototypový enkodér | `LaskaKit Rotační encoder s tlačítkem a RC s filtrem`, `LA132020` | `48 Kč` |
| Panelové tlačítko `16 mm` | `Adafruit 16mm Panel Mount Momentary Pushbutton`, Product ID `1505/1445/...` | `USD 0.95 / ks` |
| Jumper wires | `Adafruit Premium Male/Male 40x6"`, Product ID `758/3142` | `USD 3.95` |
| Prototypovací PCB | `Adafruit Perma-Proto Quarter-sized 3-pack`, Product ID `589` | `USD 8.50 / 3 ks` |
| Krabička | `Hammond 1591` série | cena dle varianty a distributora |
| Robustnější enkodér | `Bourns PEC11R` | cena dle konkrétní konfigurace a distributora |
| `ESP32` dev board | `LOLIN/Wemos S2 Mini` | cena dle distributora |

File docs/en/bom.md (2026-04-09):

# Bill of Materials

This bill of materials is prepared for the current `Bose SoundTouch SA-5` controller using an `ESP32`, `OLED`, a rotary encoder with push switch, and a single status LED.

## Variant A: Quick Prototype On The Desk

| Item | Qty | Recommended Type | Note |
|---|---:|---|---|
| `ESP32` development board | 1 | `LOLIN/Wemos S2 Mini` | Default board for the first prototype |
| OLED display | 1 | `SSD1306 0.96" 128x64 I2C` | 4 wires, simple wiring |
| Rotary encoder | 1 | LaskaKit `Rotacni encoder s tlacitkem a RC s filtrem`, `LA132020` | Default choice for the first prototype |
| Encoder knob | 1 | according to the selected encoder shaft | Typically `6 mm` |
| Status LED | 1 | standard single-color LED | Lit only in the `on` state |
| LED resistor | 1 | `220R` to `1k` | In series with the LED |
| Breadboard | 1 | half-size or similar | For initial bring-up |
| Jumper wires | 1 set | `Dupont` / breadboard wires | Male-female or male-male depending on the board |
| USB cable | 1 | according to the board, typically `USB-C` for `LOLIN/Wemos S2 Mini` | Power and flashing |
| `5 V USB` power supply | 1 | standard USB adapter | A phone charger is enough for a prototype |

## Variant B: Cleaner Enclosure Build

| Item | Qty | Recommended Type | Note |
|---|---:|---|---|
| `ESP32` development board | 1 | same as the prototype | Can remain in the final unit |
| OLED display | 1 | `SSD1306 0.96" 128x64 I2C` | Cut a panel window for it |
| Rotary encoder | 1 | `Bourns PEC11R` | Better mechanical feel |
| Encoder knob | 1 | panel knob | Choose to match style and shaft |
| Status LED | 1 | single-color LED | For `on` indication |
| LED resistor | 1 | `220R` to `1k` | In series with the LED |
| Prototype PCB | 1 | `Perma-Proto` or generic perfboard | For more permanent internal wiring |
| Enclosure | 1 | plastic `ABS` box | For panel mounting and protection |
| Standoffs / spacers | 4 | `M2.5` or `M3` | According to display and board mounting holes |
| Screws and nuts | set | `M2.5/M3` | For mounting in the enclosure |
| 24 to 26 AWG wire | 1 set | stranded or solid | For internal wiring |
| Connectors / pin headers | as needed | `2.54 mm` | Makes servicing and replacement easier |
| `5 V USB` source | 1 | permanently connected adapter | Final unit power supply |

## Recommended Specific Parts

### `ESP32`

- preferred type for the current prototype: `LOLIN/Wemos S2 Mini`
- alternative: another quality `ESP32` or `ESP32-S2` dev board with `3.3 V` logic and exposed GPIOs

Notes:

- the current firmware is adapted for `LOLIN/Wemos S2 Mini`
- the default `PlatformIO` build target is `lolin_s2_mini`

### OLED

- recommended module: `SSD1306 128x64`, `0.96"`, `I2C`
- prefer a module that reliably works at `3.3 V`

### Encoder

- for the prototype: LaskaKit `Rotacni encoder s tlacitkem a RC s filtrem`, `LA132020`
- prototype parameters: `20 pulses per revolution`, integrated push button, RC noise filter
- for a more finished build: `Bourns PEC11R`
- reason: the RC-filtered module is convenient for fast `ESP32` bring-up, while `Bourns` is mechanically better for a finished device

### Status LED

- recommended variant: a single-color LED, typically green
- it is lit only when Bose is powered on and available

## Required Vs Optional Parts

### Required For A Working Prototype

- `ESP32`
- `OLED`
- encoder
- encoder with push switch
- status LED
- 1 LED resistor
- wires
- power supply

### Optional But Recommended

- prototype PCB
- panel mount buttons
- encoder knob
- enclosure
- standoffs

## Pins And BOM Mapping

Default firmware pinout:

- `GPIO33` -> `OLED SDA`
- `GPIO35` -> `OLED SCL`
- `GPIO7` -> `Encoder A`
- `GPIO9` -> `Encoder B`
- `GPIO11` -> `Encoder SW`
- `GPIO18` -> `Status LED`

Wiring details are in [wiring.md](/Users/peny/Development/Projects/boser-remote-control/docs/en/wiring.md).

## Purchasing Recommendations

- do not buy a custom PCB for the first prototype
- start with the existing `LOLIN/Wemos S2 Mini` you already have
- if you are not sure about the mechanics yet, use cheaper generic buttons for the prototype and buy better panel parts for the final enclosure later
- if the device will sit in a metal case, expect weaker `Wi-Fi` and possibly adjust `ESP32` placement

## Reference Parts And Approximate Prices

Below are examples of currently traceable parts that match this design. Prices are indicative only and may vary by distributor, tax, and shipping.

| Item | Example | Approx. |
|---|---|---:|
| OLED `128x64 I2C` | `Adafruit 0.96" SSD1306`, Product ID `326` | `USD 17.50` |
| Prototype encoder | `LaskaKit Rotacni encoder s tlacitkem a RC s filtrem`, `LA132020` | `48 CZK` |
| `16 mm` panel button | `Adafruit 16mm Panel Mount Momentary Pushbutton`, Product ID `1505/1445/...` | `USD 0.95 / pc` |
| Jumper wires | `Adafruit Premium Male/Male 40x6"`, Product ID `758/3142` | `USD 3.95` |
| Prototype PCB | `Adafruit Perma-Proto Quarter-sized 3-pack`, Product ID `589` | `USD 8.50 / 3 pcs` |
| Enclosure | `Hammond 1591` series | price depends on variant and distributor |
| More robust encoder | `Bourns PEC11R` | price depends on exact configuration and distributor |
| `ESP32` dev board | `LOLIN/Wemos S2 Mini` | price depends on distributor |

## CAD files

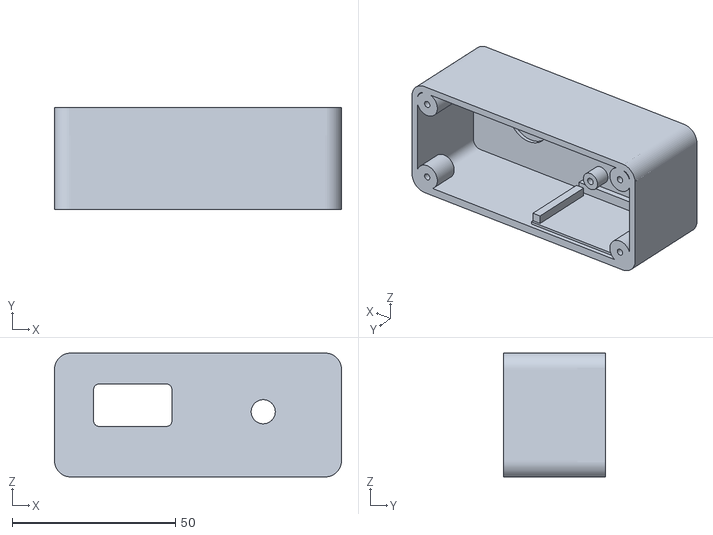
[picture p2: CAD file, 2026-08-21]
cad/compact-landscape-body.stl
88.0 x 31.2 x 38.0

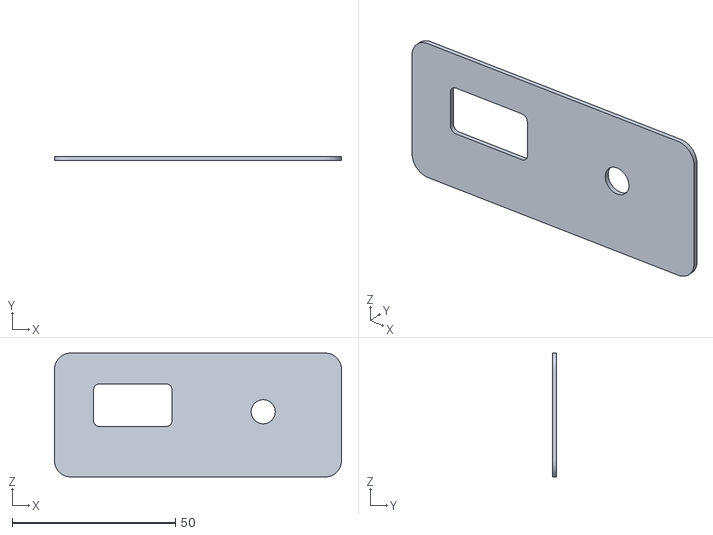
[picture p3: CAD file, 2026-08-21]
cad/compact-landscape-panel-layout.stl
88.0 x 1.20 x 38.0

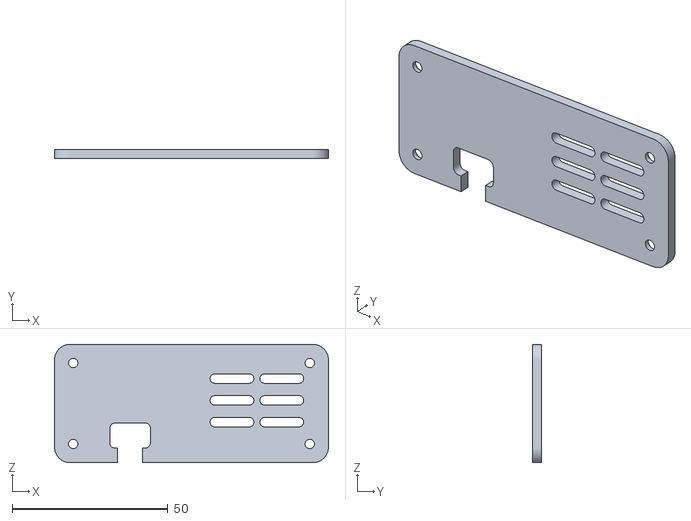
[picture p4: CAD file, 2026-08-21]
cad/compact-landscape-rear-lid.stl
88.0 x 2.80 x 38.0

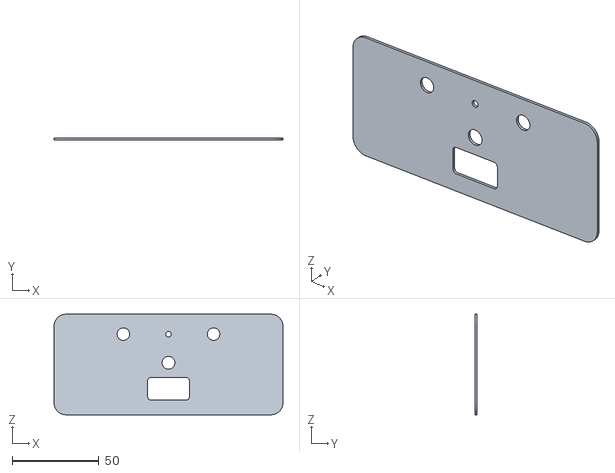
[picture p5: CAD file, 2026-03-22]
cad/panel-layout.stl
132.0 x 1.20 x 58.0

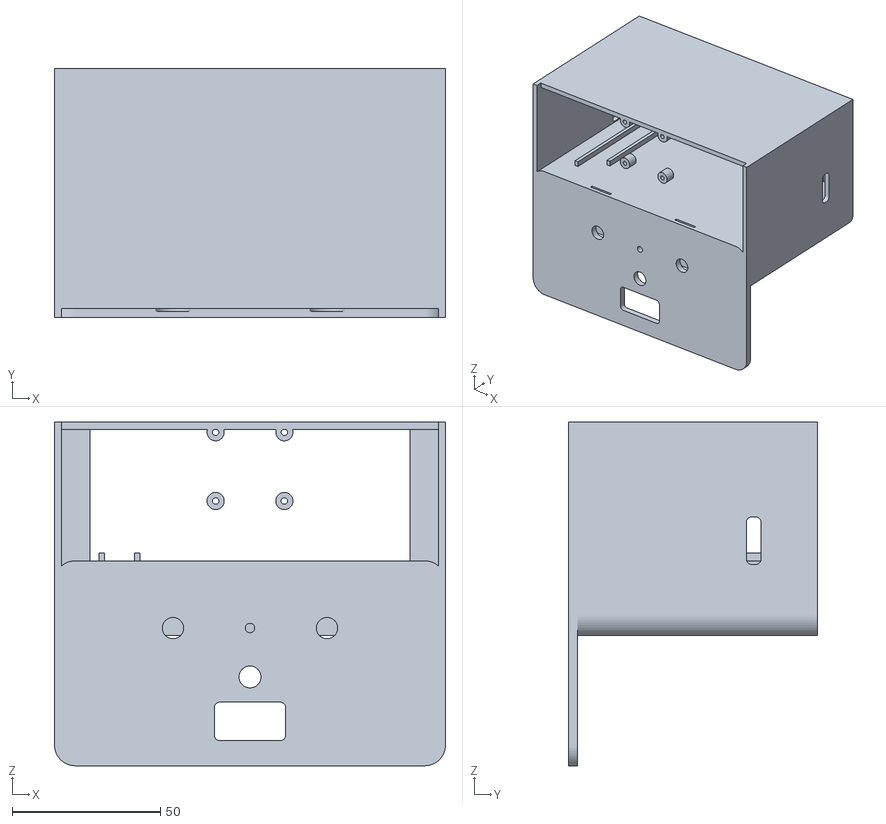
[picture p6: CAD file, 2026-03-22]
cad/body.stl
132.0 x 84.0 x 116.0

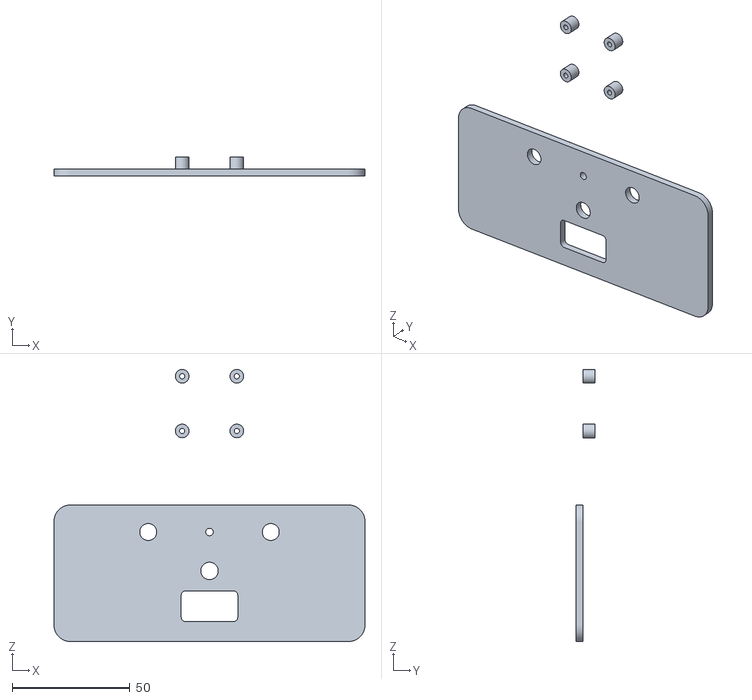
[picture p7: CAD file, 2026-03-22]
cad/front-panel.stl
132.0 x 8.20 x 115.5

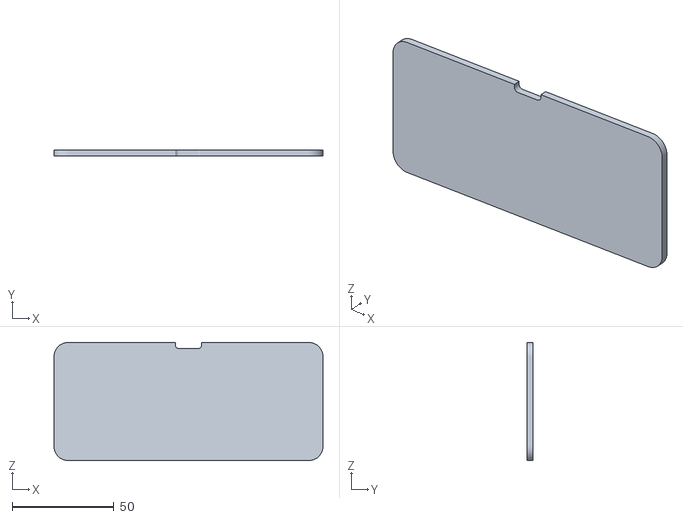
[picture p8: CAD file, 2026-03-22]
cad/rear-lid.stl
132.0 x 3.00 x 58.0

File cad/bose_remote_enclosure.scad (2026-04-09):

$fn = 48;

part = "assembly"; // body, rear_lid, panel_layout, assembly
show_reference_hardware = true;

// Main envelope sized for OLED + encoder + status LED only.
outer_width = 92;
outer_depth = 76;
outer_height = 54;
corner_radius = 6.5;
wall = 2.4;
floor_thickness = 2.8;
front_panel_thickness = 3.0;
rear_lid_thickness = 3.0;

// Front panel layout: vertically centered stack.
oled_center = [outer_width / 2, 39.0];
oled_window = [24, 13];
oled_board = [27.4, 27.8];
oled_hole_spacing = [23.2, 23.2];
oled_mount_hole_d = 2.2;
oled_standoff_d = 5.8;
oled_backoff_from_panel = 5.2;

encoder_center = [outer_width / 2, 22.0];
encoder_panel_hole_d = 7.4;
encoder_relief_d = 15;
encoder_relief_depth = 1.2;

led_center = [outer_width / 2, 8.5];
led_hole_d = 2.2;
led_relief_d = 6.8;
led_relief_depth = 1.6;

// Rear lid and USB cable routing
rear_frame_depth = 8.0;
rear_frame_side_w = 12.0;
rear_opening_height = outer_height - wall;
rear_screw_hole_d = 3.2;
rear_screw_head_d = 6.4;
rear_screw_head_depth = 1.8;
rear_screw_x = 6.4;
rear_screw_z = [12, 42];
usb_opening = [13.0, 8.0];
usb_cable_slot_w = 8.0;
usb_slot_center_z = 8.8;
rear_vent = [7.0, 12.0];
rear_vent_x_offset = 20;

// S2 Mini tray
s2_board = [25.6, 34.6, 1.6]; // x, y, z; USB at rear on +Y edge
s2_floor_z = 5.0;
s2_rear_gap = 1.6;
s2_rail_width = 2.8;
s2_rail_capture = 1.2;
s2_entry_clearance = 0.6;

// Cable routing fences
cable_fence_thickness = 1.8;
cable_fence_height = 11;
cable_lane_x = 11;
cable_lane_w = 10;

module rounded_rect_2d(size, radius) {
  x = size[0];
  y = size[1];
  hull() {
    for (ix = [radius, x - radius]) {
      for (iy = [radius, y - radius]) {
        translate([ix, iy]) circle(r = radius);
      }
    }
  }
}

module rounded_box_xz(size, radius) {
  rotate([-90, 0, 0])
    linear_extrude(height = size[1])
      rounded_rect_2d([size[0], size[2]], radius);
}

function body_inner_radius() = max(corner_radius - wall, 1.5);
function rear_screw_positions() = [
  [rear_screw_x, rear_screw_z[0]],
  [rear_screw_x, rear_screw_z[1]],
  [outer_width - rear_screw_x, rear_screw_z[0]],
  [outer_width - rear_screw_x, rear_screw_z[1]]
];

function s2_origin() = [
  outer_width / 2 - s2_board[0] / 2,
  outer_depth - rear_lid_thickness - s2_rear_gap - s2_board[1],
  s2_floor_z
];

module front_panel_cutouts_2d() {
  translate([
    oled_center[0] - oled_window[0] / 2,
    oled_center[1] - oled_window[1] / 2
  ])
    rounded_rect_2d(oled_window, 1.8);

  translate([encoder_center[0], encoder_center[1]])
    circle(d = encoder_panel_hole_d);

  translate([led_center[0], led_center[1]])
    circle(d = led_hole_d);
}

module oled_standoffs() {
  offsets = [
    [-oled_hole_spacing[0] / 2, -oled_hole_spacing[1] / 2],
    [ oled_hole_spacing[0] / 2, -oled_hole_spacing[1] / 2],
    [-oled_hole_spacing[0] / 2,  oled_hole_spacing[1] / 2],
    [ oled_hole_spacing[0] / 2,  oled_hole_spacing[1] / 2]
  ];

  for (offset = offsets) {
    translate([
      oled_center[0] + offset[0],
      front_panel_thickness,
      oled_center[1] + offset[1]
    ]) {
      rotate([-90, 0, 0]) {
        difference() {
          cylinder(h = oled_backoff_from_panel, d = oled_standoff_d);
          translate([0, 0, -0.2])
            cylinder(h = oled_backoff_from_panel + 0.4, d = oled_mount_hole_d);
        }
      }
    }
  }
}

module front_panel_reliefs() {
  translate([encoder_center[0], front_panel_thickness - encoder_relief_depth, encoder_center[1]])
    rotate([-90, 0, 0])
      cylinder(h = encoder_relief_depth + 0.1, d = encoder_relief_d);

  translate([led_center[0], front_panel_thickness - led_relief_depth, led_center[1]])
    rotate([-90, 0, 0])
      cylinder(h = led_relief_depth + 0.1, d = led_relief_d);
}

module rear_frame_side_rails() {
  translate([0, outer_depth - rear_frame_depth, 0])
    cube([rear_frame_side_w, rear_frame_depth, outer_height]);
  translate([outer_width - rear_frame_side_w, outer_depth - rear_frame_depth, 0])
    cube([rear_frame_side_w, rear_frame_depth, outer_height]);
}

module rear_opening() {
  translate([
    rear_frame_side_w,
    outer_depth - rear_frame_depth - 0.1,
    0
  ])
    cube([
      outer_width - 2 * rear_frame_side_w,
      rear_frame_depth + 0.2,
      rear_opening_height
    ]);
}

module rear_screw_pilots() {
  for (pos = rear_screw_positions()) {
    translate([pos[0], outer_depth - rear_frame_depth - 0.1, pos[1]])
      rotate([90, 0, 0])
        cylinder(h = rear_frame_depth + 0.2, d = 2.6);
  }
}

module s2_tray() {
  origin = s2_origin();
  rail_len = s2_board[1] - 4;

  for (x_pos = [origin[0], origin[0] + s2_board[0] + s2_entry_clearance - s2_rail_width]) {
    translate([x_pos, origin[1] + 2, floor_thickness])
      cube([s2_rail_width, rail_len, s2_floor_z - floor_thickness]);
    translate([x_pos, origin[1] + 2, s2_floor_z])
      cube([s2_rail_width, rail_len, s2_rail_capture]);
  }

  translate([origin[0], origin[1], floor_thickness])
    cube([s2_board[0] + s2_entry_clearance, 2.0, s2_floor_z + s2_rail_capture - floor_thickness]);
}

module cable_guides() {
  translate([cable_lane_x, 14, floor_thickness])
    cube([cable_fence_thickness, outer_depth - 24, cable_fence_height]);
  translate([cable_lane_x + cable_lane_w, 24, floor_thickness])
    cube([cable_fence_thickness, outer_depth - 34, cable_fence_height]);
}

module side_reliefs() {
  for (x_pos = [0, outer_width - wall - 0.1]) {
    translate([x_pos, outer_depth - 24, 26])
      rotate([0, 90, 0])
        linear_extrude(height = wall + 0.2)
          rounded_rect_2d([16, 5], 1.8);
  }
}

module body() {
  difference() {
    union() {
      rounded_box_xz([outer_width, front_panel_thickness, outer_height], corner_radius);
      rounded_box_xz([outer_width, outer_depth, floor_thickness], corner_radius);
      translate([0, 0, 0]) cube([wall, outer_depth, outer_height]);
      translate([outer_width - wall, 0, 0]) cube([wall, outer_depth, outer_height]);
      translate([0, front_panel_thickness, outer_height - wall])
        cube([outer_width, outer_depth - front_panel_thickness, wall]);
      translate([0, outer_depth - rear_frame_depth, 0])
        cube([rear_frame_side_w, rear_frame_depth, outer_height]);
      translate([outer_width - rear_frame_side_w, outer_depth - rear_frame_depth, 0])
        cube([rear_frame_side_w, rear_frame_depth, outer_height]);

      oled_standoffs();
      s2_tray();
      cable_guides();
    }

    translate([0, -0.1, 0])
      rotate([-90, 0, 0])
        linear_extrude(height = front_panel_thickness + 0.2)
          front_panel_cutouts_2d();

    front_panel_reliefs();
    rear_screw_pilots();
    rear_opening();
    side_reliefs();
  }
}

module rear_lid() {
  difference() {
    rounded_box_xz([outer_width, rear_lid_thickness, outer_height], corner_radius);

    for (pos = rear_screw_positions()) {
      translate([pos[0], -0.1, pos[1]])
        rotate([-90, 0, 0])
          cylinder(h = rear_lid_thickness + 0.2, d = rear_screw_hole_d);

      translate([pos[0], rear_screw_head_depth, pos[1]])
        rotate([-90, 0, 0])
          cylinder(h = rear_screw_head_depth + 0.2, d = rear_screw_head_d);
    }

    translate([
      outer_width / 2 - usb_opening[0] / 2,
      -0.1,
      usb_slot_center_z - usb_opening[1] / 2
    ])
      rotate([-90, 0, 0])
        linear_extrude(height = rear_lid_thickness + 0.2)
          rounded_rect_2d(usb_opening, 1.8);

    // Open-bottom slot so the lid can close around an already connected USB cable.
    translate([
      outer_width / 2 - usb_cable_slot_w / 2,
      -0.1,
      0
    ])
      cube([usb_cable_slot_w, rear_lid_thickness + 0.2, usb_slot_center_z]);

    for (x_offset = [-rear_vent_x_offset, rear_vent_x_offset]) {
      translate([
        outer_width / 2 + x_offset - rear_vent[0] / 2,
        -0.1,
        22
      ])
        rotate([-90, 0, 0])
          linear_extrude(height = rear_lid_thickness + 0.2)
            rounded_rect_2d(rear_vent, 1.4);
    }
  }
}

module panel_layout() {
  difference() {
    rounded_box_xz([outer_width, 1.2, outer_height], corner_radius);

    translate([0, -0.1, 0])
      rotate([-90, 0, 0])
        linear_extrude(height = 1.4)
          front_panel_cutouts_2d();
  }
}

module reference_hardware() {
  color([0.10, 0.45, 0.85, 0.55])
    translate([
      oled_center[0] - oled_board[0] / 2,
      front_panel_thickness + oled_backoff_from_panel - 1.6,
      oled_center[1] - oled_board[1] / 2
    ])
      cube([oled_board[0], 1.6, oled_board[1]]);

  color([0.20, 0.75, 0.30, 0.55])
    translate(s2_origin())
      cube([s2_board[0], s2_board[1], s2_board[2]]);

  color([0.75, 0.75, 0.75, 0.5])
    translate([encoder_center[0], front_panel_thickness, encoder_center[1]])
      rotate([-90, 0, 0])
        cylinder(h = 18, d = 17);

  color([0.95, 0.2, 0.2, 0.45])
    translate([led_center[0], front_panel_thickness, led_center[1]])
      rotate([-90, 0, 0])
        cylinder(h = 4, d = 4.8);
}
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

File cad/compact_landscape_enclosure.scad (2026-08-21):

$fn = 56;

part = "assembly"; // body, rear_lid, panel_layout, assembly
show_reference_hardware = true;

// Low-profile landscape enclosure: OLED on the left, encoder knob on the right.
outer_width = 88;
outer_depth = 34;
outer_height = 38;
corner_radius = 5.0;
wall = 2.2;
bottom_thickness = 2.6;
front_panel_thickness = 3.0;
rear_lid_thickness = 2.8;
body_depth = outer_depth - rear_lid_thickness;

// Front panel layout, measured in X/Z from the lower-left front corner.
oled_center = [24.0, 22.0];
oled_window = [24.0, 13.0];
oled_board = [27.4, 27.8];
oled_hole_spacing = [23.2, 23.2];
oled_mount_hole_d = 2.2;
oled_standoff_d = 5.6;
oled_backoff_from_panel = 5.2;

encoder_center = [64.0, 20.0];
encoder_panel_hole_d = 7.4;
encoder_relief_d = 15.5;
encoder_relief_depth = 1.2;
encoder_body_d = 17.0;
encoder_body_depth = 18.0;
knob_d = 22.0;
knob_depth = 14.0;

// LOLIN/Wemos S2 Mini lying flat on a left-side tray, USB-C facing rear.
s2_board = [34.6, 25.6, 1.6]; // x, y, z
s2_origin = [7.0, 4.1, 5.0];
s2_tray_clearance = 0.5;
s2_tray_floor_h = 0.8;
s2_rail_width = 2.8;
s2_rail_capture = 1.1;
s2_front_stop_h = 4.0;
s2_front_stop_thickness = 2.0;

usb_opening = [13.0, 8.0];
usb_slot_center_x = s2_origin[0] + s2_board[0] / 2;
usb_slot_center_z = 8.7;
usb_cable_slot_w = 8.0;

// Rear lid screws.
rear_screw_hole_d = 3.0;
rear_screw_pilot_d = 2.1;
rear_screw_head_d = 6.2;
rear_screw_head_depth = 1.6;
rear_screw_boss_d = 8.0;
rear_screw_boss_depth = 8.5;
rear_screw_x = [6.0, outer_width - 6.0];
rear_screw_z = [6.0, outer_height - 6.0];

// Small rear vents, kept away from the S2 Mini antenna area.
rear_vent = [14.0, 3.0];
rear_vent_x = [57.0, 73.0];
rear_vent_z = [13.0, 20.0, 27.0];

module rounded_rect_2d(size, radius) {
  x = size[0];
  y = size[1];
  hull() {
    for (ix = [radius, x - radius]) {
      for (iy = [radius, y - radius]) {
        translate([ix, iy]) circle(r = radius);
      }
    }
  }
}

module rounded_box_xz(size, radius) {
  x = size[0];
  y = size[1];
  z = size[2];

  hull() {
    for (ix = [radius, x - radius]) {
      for (iz = [radius, z - radius]) {
        translate([ix, 0, iz])
          rotate([-90, 0, 0])
            cylinder(h = y, r = radius);
      }
    }
  }
}

function inner_radius() = max(corner_radius - wall, 1.2);

function rear_screw_positions() = [
  [rear_screw_x[0], rear_screw_z[0]],
  [rear_screw_x[0], rear_screw_z[1]],
  [rear_screw_x[1], rear_screw_z[0]],
  [rear_screw_x[1], rear_screw_z[1]]
];

module extrude_panel_y(height) {
  translate([0, height, 0])
    rotate([90, 0, 0])
      linear_extrude(height = height)
        children();
}

module front_panel_cutouts_2d() {
  translate([
    oled_center[0] - oled_window[0] / 2,
    oled_center[1] - oled_window[1] / 2
  ])
    rounded_rect_2d(oled_window, 1.7);

  translate(encoder_center)
    circle(d = encoder_panel_hole_d);
}

module oled_standoffs() {
  offsets = [
    [-oled_hole_spacing[0] / 2, -oled_hole_spacing[1] / 2],
    [ oled_hole_spacing[0] / 2, -oled_hole_spacing[1] / 2],
    [-oled_hole_spacing[0] / 2,  oled_hole_spacing[1] / 2],
    [ oled_hole_spacing[0] / 2,  oled_hole_spacing[1] / 2]
  ];

  for (offset = offsets) {
    translate([
      oled_center[0] + offset[0],
      front_panel_thickness - 0.15,
      oled_center[1] + offset[1]
    ])
      rotate([-90, 0, 0])
        difference() {
          cylinder(h = oled_backoff_from_panel + 0.15, d = oled_standoff_d);
          translate([0, 0, -0.2])
            cylinder(h = oled_backoff_from_panel + 0.6, d = oled_mount_hole_d);
        }
  }
}

module front_panel_reliefs() {
  translate([
    encoder_center[0],
    front_panel_thickness - encoder_relief_depth,
    encoder_center[1]
  ])
    rotate([-90, 0, 0])
      cylinder(h = encoder_relief_depth + 0.1, d = encoder_relief_d);

}

module rear_screw_bosses() {
  for (pos = rear_screw_positions()) {
    translate([pos[0], body_depth - rear_screw_boss_depth, pos[1]])
      rotate([-90, 0, 0])
        cylinder(h = rear_screw_boss_depth, d = rear_screw_boss_d);

    if (pos[0] < outer_width / 2) {
      translate([0, body_depth - rear_screw_boss_depth, pos[1] - 1.5])
        cube([pos[0], rear_screw_boss_depth, 3.0]);
    } else {
      translate([pos[0], body_depth - rear_screw_boss_depth, pos[1] - 1.5])
        cube([outer_width - pos[0], rear_screw_boss_depth, 3.0]);
    }

    if (pos[1] < outer_height / 2) {
      translate([pos[0] - 1.5, body_depth - rear_screw_boss_depth, 0])
        cube([3.0, rear_screw_boss_depth, pos[1]]);
    } else {
      translate([pos[0] - 1.5, body_depth - rear_screw_boss_depth, pos[1]])
        cube([3.0, rear_screw_boss_depth, outer_height - pos[1]]);
    }
  }
}

module rear_screw_pilots() {
  for (pos = rear_screw_positions()) {
    translate([pos[0], body_depth - rear_screw_boss_depth - 0.2, pos[1]])
      rotate([-90, 0, 0])
        cylinder(h = rear_screw_boss_depth + 0.5, d = rear_screw_pilot_d);
  }
}

module s2_cradle() {
  tray_size = [
    s2_board[0] + 2 * s2_tray_clearance,
    s2_board[1] + s2_tray_clearance
  ];
  tray_origin = [
    s2_origin[0] - s2_tray_clearance,
    s2_origin[1] - s2_tray_clearance
  ];
  rail_y = s2_origin[1] + s2_front_stop_thickness + 0.8;
  rail_len = s2_board[1] - s2_front_stop_thickness - 1.6;
  rail_base_h = s2_origin[2] - bottom_thickness;

  translate([tray_origin[0], tray_origin[1], bottom_thickness - 0.2])
    cube([tray_size[0], tray_size[1], s2_tray_floor_h + 0.2]);

  for (x_pos = [
    s2_origin[0] - s2_tray_clearance,
    s2_origin[0] + s2_board[0] + s2_tray_clearance - s2_rail_width
  ]) {
    translate([x_pos, rail_y, bottom_thickness - 0.2])
      cube([s2_rail_width, rail_len, rail_base_h + 0.2]);

    translate([x_pos, rail_y, s2_origin[2]])
      cube([s2_rail_width, rail_len, s2_rail_capture]);
  }

  // Front stop: the board slides in from the open rear and stops here.
  translate([
    s2_origin[0] - s2_tray_clearance,
    s2_origin[1] - s2_tray_clearance,
    bottom_thickness - 0.2
  ])
    cube([
      s2_board[0] + 2 * s2_tray_clearance,
      s2_front_stop_thickness,
      s2_front_stop_h + 0.2
    ]);
}

module cable_lane() {
  translate([
    usb_slot_center_x - usb_cable_slot_w / 2,
    body_depth - 5.5,
    bottom_thickness
  ])
    cube([usb_cable_slot_w, 5.7, usb_slot_center_z - bottom_thickness + 3.2]);
}

module body_shell() {
  difference() {
    rounded_box_xz([outer_width, body_depth, outer_height], corner_radius);

    translate([wall, front_panel_thickness, bottom_thickness])
      rounded_box_xz([
        outer_width - 2 * wall,
        body_depth - front_panel_thickness + 0.2,
        outer_height - bottom_thickness - wall
      ], inner_radius());
  }
}

module body() {
  difference() {
    union() {
      body_shell();
      oled_standoffs();
      rear_screw_bosses();
      s2_cradle();
    }

    translate([0, -0.2, 0])
      extrude_panel_y(front_panel_thickness + 0.4)
        front_panel_cutouts_2d();

    front_panel_reliefs();
    rear_screw_pilots();
  }
}

module rear_lid_cutouts_2d() {
  for (pos = rear_screw_positions()) {
    translate(pos)
      circle(d = rear_screw_hole_d);
  }

  translate([
    usb_slot_center_x - usb_opening[0] / 2,
    usb_slot_center_z - usb_opening[1] / 2
  ])
    rounded_rect_2d(usb_opening, 1.6);

  // Open-bottom cable slot for closing the lid around a connected USB cable.
  translate([
    usb_slot_center_x - usb_cable_slot_w / 2,
    0
  ])
    square([usb_cable_slot_w, usb_slot_center_z]);

  for (x_pos = rear_vent_x) {
    for (z_pos = rear_vent_z) {
      translate([x_pos - rear_vent[0] / 2, z_pos - rear_vent[1] / 2])
        rounded_rect_2d(rear_vent, 1.4);
    }
  }
}

module rear_lid_countersinks() {
  for (pos = rear_screw_positions()) {
    translate([pos[0], rear_lid_thickness - rear_screw_head_depth, pos[1]])
      rotate([-90, 0, 0])
        cylinder(h = rear_screw_head_depth + 0.2, d = rear_screw_head_d);
  }
}

module rear_lid() {
  difference() {
    rounded_box_xz([outer_width, rear_lid_thickness, outer_height], corner_radius);

    translate([0, -0.1, 0])
      extrude_panel_y(rear_lid_thickness + 0.2)
        rear_lid_cutouts_2d();

    rear_lid_countersinks();
  }
}

module panel_layout() {
  difference() {
    rounded_box_xz([outer_width, 1.2, outer_height], corner_radius);

    translate([0, -0.1, 0])
      extrude_panel_y(1.4)
        front_panel_cutouts_2d();
  }
}

module reference_hardware() {
  color([0.10, 0.45, 0.85, 0.55])
    translate([
      oled_center[0] - oled_board[0] / 2,
      front_panel_thickness + oled_backoff_from_panel - 1.6,
      oled_center[1] - oled_board[1] / 2
    ])
      cube([oled_board[0], 1.6, oled_board[1]]);

  color([0.20, 0.75, 0.30, 0.55])
    translate(s2_origin)
      cube(s2_board);

  color([0.75, 0.75, 0.75, 0.5])
    translate([encoder_center[0], front_panel_thickness, encoder_center[1]])
      rotate([-90, 0, 0])
        cylinder(h = encoder_body_depth, d = encoder_body_d);
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

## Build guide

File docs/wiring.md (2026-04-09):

# Zapojení a spojení vodičů

Tento dokument popisuje elektrické zapojení `v1` prototypu. Výchozí referenční deska je `LOLIN/Wemos S2 Mini`. Bose zesilovač se k `ESP32` nepřipojuje žádným vodičem. Komunikace s `SA-5` probíhá výhradně po `Wi‑Fi`.

## Cely pinout a schema

Projektovy pinout LOLIN Wemos S2 Mini a napojene komponenty

Obrazek ukazuje cely pinout `LOLIN/Wemos S2 Mini`. Jen u pinu pouzitych v tomto projektu je dopsane konkretni zapojeni `OLED`, enkoderu, tlacitka encoderu a stavove LED.

## Základní princip

- `ESP32` čte lokální ovládací prvky
- `ESP32` zobrazuje stav na `OLED`
- `ESP32` posílá příkazy do `Bose SA-5` přes síť

To znamená, že na stole nebo v krabici existují jen tyto elektrické části:

- `ESP32` vývojová deska
- `OLED SSD1306 128x64 I2C`
- rotační enkodér
- tlačítko v encoderu
- jedna stavová LED

## Pin mapa

Výchozí piny jsou definované v [PinConfig.h](/Users/peny/Development/Projects/boser-remote-control/include/PinConfig.h).

| Funkce | ESP32 pin | Poznámka |
|---|---:|---|
| OLED `SDA` | `GPIO33` | `I2C` data |
| OLED `SCL` | `GPIO35` | `I2C` clock |
| Encoder `A` | `GPIO7` | kvadraturní vstup |
| Encoder `B` | `GPIO9` | kvadraturní vstup |
| Tlačítko encoderu `SW` | `GPIO11` | aktivní v `LOW`, zároveň servisní hold při bootu |
| Stavová LED | `GPIO18` | výstup pro LED |

## Napájení

### Varianta s `LOLIN/Wemos S2 Mini`

- `ESP32` napájet z `USB 5 V`
- `OLED` napájet z `3.3 V` desky
- tlačítka a enkodér jsou pasivní vstupy proti `GND`

### Důležité

- nepřivádět `5 V` přímo na `GPIO`
- pokud má konkrétní `OLED` modul jen `5 V` logiku, je nutné ověřit kompatibilitu s `3.3 V`
- společná zem `GND` musí být propojena mezi `ESP32`, `OLED`, enkodérem a tlačítky

## Zapojení vodičů

### OLED `SSD1306 I2C`

| OLED pin | Připojit na |
|---|---|
| `VCC` | `3.3 V` |
| `GND` | `GND` |
| `SDA` | `GPIO33` |
| `SCL` | `GPIO35` |

## Rotační enkodér

Typicky má piny `A`, `B`, `COM` a někdy i vestavěný stisk `SW`.

| Encoder pin | Připojit na |
|---|---|
| `A` | `GPIO7` |
| `B` | `GPIO9` |
| `COM` | `GND` |
| `SW` | `GPIO11` |

Firmware používá interní pull-upy, takže není nutné přidávat externí rezistory pro běžný mechanický enkodér.

## Tlačítko encoderu

Vestavěné tlačítko encoderu je zapojené jako jednoduchý spínač proti zemi.

| Kontakt | Připojit na |
|---|---|
| `SW` | `GPIO11` |
| druhý kontakt tlačítka | `GND` |

Firmware používá `INPUT_PULLUP`, takže tlačítko je v klidu `HIGH` a po stisku přejde do `LOW`.

## Stavová LED

Firmware počítá s jednou samostatně řízenou LED.

| LED kontakt | Připojit na |
|---|---|
| `Anoda` | `GPIO18` -> samostatny seriovy rezistor -> LED |
| `Katoda` | `GND` |

Poznámka:

- firmware má výchozí logiku `active HIGH`
- pokud použiješ jiný aktivní stav, změň `STATUS_LED_ACTIVE_HIGH` v [PinConfig.h](/Users/peny/Development/Projects/boser-remote-control/include/PinConfig.h)
- rezistor patri mezi `GPIO18` a LED
- typicky pouzij `220R` az `1k`, pro prototyp rozumne treba `330R`

## Jednoduché blokové schéma

```text
                 +----------------------+
                 |   Bose SoundTouch    |
                 |       SA-5           |
                 |   Wi-Fi only link    |
                 +----------^-----------+
                            |
                         Wi-Fi LAN
                            |
+--------------------------------------------------+
|                      ESP32                       |
|                                                  |
|  GPIO33 <------ SDA -------- OLED 128x64         |
|  GPIO35 <------ SCL -------- OLED 128x64         |
|  3V3    ------> VCC -------- OLED                |
|  GND    ------> GND -------- OLED                |
|                                                  |
|  GPIO7  <------ A ---------- Encoder             |
|  GPIO9  <------ B ---------- Encoder             |
|  GND    ------> COM -------- Encoder             |
|                                                  |
|  GPIO11 <------ Encoder SW -----> GND            |
|  GPIO18 ------> [330R] --> LED anoda           |
|  GND    ------> LED katoda                     |
|                                                  |
+--------------------------------------------------+
```

## Doporučení pro reálný spoj nebo krabičku

- vést `I2C` vodiče co nejkratší
- tlačítka a enkodér připojit stíněně nebo aspoň čistě vedenými vodiči, pokud budou delší
- pokud bude zařízení v kovové krabici, ověřit kvalitu `Wi‑Fi`
- `ESP32` umístit tak, aby anténa nebyla zakrytá kovem

## Co není součást zapojení `v1`

- žádné relé pro odpojení napájení Bose
- žádný analogový audiovýstup z `ESP32`
- žádné připojení na `AUX` konektory Bose
- žádný fyzický zásah do elektroniky `SA-5`

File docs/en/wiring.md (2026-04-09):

# Wiring and Connections

This document describes the electrical wiring of the `v1` prototype. The default reference board is `LOLIN/Wemos S2 Mini`. The Bose amplifier is not connected to the `ESP32` by any wire. Communication with the `SA-5` is done exclusively over `Wi-Fi`.

## Full Pinout And Diagram

Project pinout for LOLIN Wemos S2 Mini and connected components

The image shows the full `LOLIN/Wemos S2 Mini` pinout. Only the pins used by this project carry the extra wiring annotations for the `OLED`, encoder, encoder button, and status LED.

## Basic Principle

- the `ESP32` reads local controls
- the `ESP32` displays status on the `OLED`
- the `ESP32` sends commands to the `Bose SA-5` over the network

That means the only electrical parts on the desk or inside the enclosure are:

- `ESP32` development board
- `OLED SSD1306 128x64 I2C`
- rotary encoder
- encoder push button
- single status LED

## Pin Map

Default pins are defined in [PinConfig.h](/Users/peny/Development/Projects/boser-remote-control/include/PinConfig.h).

| Function | ESP32 pin | Note |
|---|---:|---|
| OLED `SDA` | `GPIO33` | `I2C` data |
| OLED `SCL` | `GPIO35` | `I2C` clock |
| Encoder `A` | `GPIO7` | quadrature input |
| Encoder `B` | `GPIO9` | quadrature input |
| Encoder button `SW` | `GPIO11` | active in `LOW`, also used as service hold during boot |
| Status LED | `GPIO18` | LED output |

## Power

### `LOLIN/Wemos S2 Mini` Variant

- power the `ESP32` from `USB 5 V`
- power the `OLED` from the board `3.3 V`
- buttons and encoder are passive inputs tied to `GND`

### Important Notes

- do not feed `5 V` directly into `GPIO`
- if a specific `OLED` module only supports `5 V` logic, verify compatibility with `3.3 V`
- common `GND` must be connected between the `ESP32`, `OLED`, encoder, and buttons

## Wire Connections

### `SSD1306 I2C` OLED

| OLED pin | Connect to |
|---|---|
| `VCC` | `3.3 V` |
| `GND` | `GND` |
| `SDA` | `GPIO33` |
| `SCL` | `GPIO35` |

## Rotary Encoder

Typical pins are `A`, `B`, `COM`, and sometimes a built-in push button `SW`.

| Encoder pin | Connect to |
|---|---|
| `A` | `GPIO7` |
| `B` | `GPIO9` |
| `COM` | `GND` |
| `SW` | `GPIO11` |

The firmware uses internal pull-ups, so external resistors are not required for a typical mechanical encoder.

## Encoder Button

The built-in encoder push button is wired as a simple switch to ground.

| Contact | Connect to |
|---|---|
| `SW` | `GPIO11` |
| other switch contact | `GND` |

The firmware uses `INPUT_PULLUP`, so the idle state is `HIGH` and a press pulls the input to `LOW`.

## Status LED

The default firmware expects one independently controlled LED.

| LED contact | Connect to |
|---|---|
| `Anode` | `GPIO18` -> dedicated series resistor -> LED |
| `Cathode` | `GND` |

Notes:

- the default firmware logic is `active HIGH`
- if you use another active state, change `STATUS_LED_ACTIVE_HIGH` in [PinConfig.h](/Users/peny/Development/Projects/boser-remote-control/include/PinConfig.h)
- the resistor belongs between `GPIO18` and the LED
- typical values are `220R` to `1k`; `330R` is a sensible prototype default

## Simple Block Diagram

```text
                 +----------------------+
                 |   Bose SoundTouch    |
                 |       SA-5           |
                 |   Wi-Fi only link    |
                 +----------^-----------+
                            |
                         Wi-Fi LAN
                            |
+--------------------------------------------------+
|                      ESP32                       |
|                                                  |
|  GPIO33 <------ SDA -------- OLED 128x64         |
|  GPIO35 <------ SCL -------- OLED 128x64         |
|  3V3    ------> VCC -------- OLED                |
|  GND    ------> GND -------- OLED                |
|                                                  |
|  GPIO7  <------ A ---------- Encoder             |
|  GPIO9  <------ B ---------- Encoder             |
|  GND    ------> COM -------- Encoder             |
|                                                  |
|  GPIO11 <------ Encoder SW -----> GND            |
|  GPIO18 ------> [330R] --> LED anode            |
|  GND    ------> LED cathode                     |
|                                                  |
+--------------------------------------------------+
```

## Recommendations For A Real Build Or Enclosure

- keep `I2C` wires as short as possible
- use clean wiring for buttons and encoder, especially if the wires are longer
- if the device goes into a metal enclosure, verify `Wi-Fi` quality
- place the `ESP32` so the antenna is not shielded by metal

## Not Part Of `v1` Wiring

- no relay for disconnecting Bose power
- no analog audio output from the `ESP32`
- no connection to Bose `AUX` connectors
- no physical modification of the `SA-5` electronics

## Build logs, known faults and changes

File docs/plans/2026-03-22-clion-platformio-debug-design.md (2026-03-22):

# CLion + PlatformIO Debug Workflow Design

## Context

Project uses `PlatformIO` with the `Arduino` framework and currently targets a generic `esp32dev` environment in [platformio.ini](/Users/peny/Development/Projects/boser-remote-control/platformio.ini). The actual hardware is an `ESP32-WROOM-32` board connected over `CP2102` serial. This setup supports flashing and serial monitoring, but it does not provide built-in `USB-JTAG`, so true breakpoint debugging in `CLion` is not available without extra hardware such as `ESP-Prog`.

The goal is not to replace `PlatformIO` or migrate to `ESP-IDF`. The goal is to make day-to-day development in `CLion` practical now, with a strong serial-debug workflow, while keeping a clean upgrade path to real `JTAG` debugging later.

## Goals

- Keep `PlatformIO` as the only build system.
- Add a clean `debug` workflow in `CLion` for build, upload, and serial monitoring.
- Improve observability through targeted firmware logs.
- Avoid invasive refactors or speculative simulator work.
- Prepare a future `JTAG` environment without requiring another redesign.

## Non-Goals

- No migration to `ESP-IDF` or plain `CMake`.
- No full software simulator of `ESP32`, OLED, encoder, and Wi-Fi stack.
- No host-side unit test framework in this phase.
- No attempt to provide breakpoint debugging on the current `CP2102`-only board.

## Recommended Approach

Use multiple `PlatformIO` environments to separate production and diagnostic use cases:

- `env:esp32dev-release`
  - default production-oriented build
  - lower log verbosity
  - normal optimization
- `env:esp32dev-debug`
  - serial-debug oriented build
  - higher log verbosity
  - monitor filters and explicit serial port setup
  - compiler flags chosen for easier diagnosis
- `env:esp32dev-jtag` or equivalent placeholder
  - reserved for future external debugger setup
  - not expected to work until extra hardware is added

`CLion` should call `PlatformIO` tasks instead of introducing a second build path. The IDE becomes a control surface for the existing firmware workflow, not a replacement for it.

## Configuration Design

### PlatformIO Environments

The current single environment should be split into named environments with shared defaults. Shared settings should include:

- `platform = espressif32`
- target board and framework
- common dependencies
- common monitor speed

Per-environment differences should then be isolated to:

- `build_flags`
- `build_type`
- `monitor_filters`
- optional `upload_port` and `monitor_port`
- future `debug_tool`, `debug_init_break`, and related debug settings

The `debug` environment should enable more firmware output, for example through:

- a higher `CORE_DEBUG_LEVEL`
- a dedicated compile-time flag such as `-DAPP_DEBUG=1`

This combination is more useful than `CORE_DEBUG_LEVEL` alone, because the current codebase does not emit enough diagnostic information on its own.

### CLion Integration

The intended `CLion` workflow is:

1. `Build Debug`
2. `Upload Debug`
3. `Monitor Debug`

This can be implemented either through the PlatformIO plugin or shell-backed run configurations that call:

```bash
pio run -e esp32dev-debug
pio run -e esp32dev-debug -t upload
pio device monitor -e esp32dev-debug
```

The same pattern applies to `release`. The important part is that `CLion` always runs the named environment explicitly, so there is no ambiguity about which flags or log level are active.

## Firmware Diagnostics Design

The firmware needs a lightweight logging layer that is easy to leave in place long term. A minimal wrapper header is enough, for example macros like:

- `LOG_INFO(...)`
- `LOG_WARN(...)`
- `LOG_ERROR(...)`
- `LOG_DEBUG(...)`

These macros should compile to serial output only when `APP_DEBUG` is enabled, or reduce verbosity in `release`. This avoids scattering raw `Serial.print` calls everywhere and keeps diagnostic behavior centrally controlled.

### Critical Log Points

Most valuable log points:

- [src/main.cpp](/Users/peny/Development/Projects/boser-remote-control/src/main.cpp)
  - boot start
  - setup mode reason
  - Wi-Fi connect attempt
  - Wi-Fi connected/disconnected transitions
  - Bose reconnect attempts
  - volume commit events
  - button actions and overlay-triggering events
- [src/BoseClient.cpp](/Users/peny/Development/Projects/boser-remote-control/src/BoseClient.cpp)
  - HTTP request path and result status
  - empty response / timeout / invalid response conditions
  - WebSocket connect, disconnect, reconnect
  - switch to polling fallback
  - scheduled refresh causes
- [src/InputController.cpp](/Users/peny/Development/Projects/boser-remote-control/src/InputController.cpp)
  - button press detection in debug mode
  - encoder delta readings when troubleshooting direction or noise

The design intent is not full tracing of every loop iteration. Logs should describe transitions and actions, not flood the serial line continuously.

## Data Flow During Debug Sessions

The operational flow in a debug session should be:

1. `CLion` builds the `esp32dev-debug` environment.
2. Firmware is uploaded to the board through serial.
3. `CLion` opens a serial monitor against the same environment.
4. Developer reproduces a scenario such as boot, setup mode, Wi-Fi reconnect, Bose connection failure, or encoder input.
5. Logs reveal the exact stage and failure mode.
6. OLED remains a secondary coarse status indicator for field use without a terminal.

This gives two layers of observability:

- detailed serial diagnostics in `CLion`
- short user-facing status on device display

## Error Handling Expectations

The design should make failure classes distinguishable. At minimum, logs should clearly separate:

- missing or invalid saved config
- forced setup mode by held power button
- Wi-Fi association failure or retry
- Bose host unreachable
- HTTP transport failure
- HTTP error status
- WebSocket disconnected and polling fallback active

This matters because the current device behavior already includes retries and fallback logic. Without explicit logs, many different failure states look identical from the outside.

## Testing and Simulation Position

This phase does not add a full simulator. For this project, a full emulator for `ESP32 + Arduino + Wi-Fi + encoder + OLED + Bose device` would be disproportionately expensive relative to the immediate benefit.

If future testing is needed before acquiring `JTAG`, the recommended next step is a mock Bose service, not a board simulator. That would let the real firmware run on real hardware while Bose endpoints such as `/info`, `/sources`, `/volume`, and `/now_playing` are simulated on the network. This is much more useful for diagnosing integration behavior than attempting to emulate the whole device stack.

## Future JTAG Upgrade Path

When an external debugger is added later, the design should extend rather than change:

- keep existing `release` and `debug` environments
- add a hardware-specific debug environment for `JTAG`
- keep the logging layer enabled in debug builds

Even after `JTAG` is available, serial logs remain useful for networking and timing-related investigation. The project should not treat logging as a temporary substitute to be removed later.

## Implementation Outline

When implementation starts, the work should proceed in this order:

1. Refactor [platformio.ini](/Users/peny/Development/Projects/boser-remote-control/platformio.ini) into shared defaults plus `release` and `debug` environments.
2. Add a small debug logging header and wire it into the firmware.
3. Insert targeted logs into boot, connectivity, Bose transport, and input handling paths.
4. Document `CLion` run configurations and serial workflow in project docs.
5. Optionally prepare a placeholder `JTAG` environment with comments explaining its future use.

## Acceptance Criteria

The design is successful when:

- firmware can be built, uploaded, and monitored from `CLion` using explicit `PlatformIO` environments
- a `debug` build emits actionable logs for boot, connectivity, Bose I/O, and input events
- `release` remains quieter and suitable for normal use
- the project structure stays on `PlatformIO`
- future `JTAG` support can be added without redesigning the workflow

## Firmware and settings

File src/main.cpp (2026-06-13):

#include <Arduino.h>
#include <ESPmDNS.h>
#include <WiFi.h>

#include "BoseClient.h"
#include "CaptivePortal.h"
#include "ConfigStore.h"
#include "ControlWebServer.h"
#include "InputController.h"
#include "OtaUpdater.h"
#include "PinConfig.h"
#include "UiRenderer.h"

#ifndef FIRMWARE_VERSION
#define FIRMWARE_VERSION "dev"
#endif

#ifndef OTA_ASSET
#define OTA_ASSET "firmware.bin"
#endif

namespace {
constexpr unsigned long kUiRefreshMs = 80;
constexpr unsigned long kWifiRetryMs = 10000;
constexpr unsigned long kBoseRetryMs = 10000;
constexpr unsigned long kVolumeCommitDelayMs = 100;
constexpr unsigned long kSourceOverlayMs = 2000;
constexpr unsigned long kActionOverlayMs = 500;
constexpr unsigned long kMenuTimeoutMs = 4000;
constexpr unsigned long kMenuAnimationMs = 140;

constexpr const char* kSelectionOnline = "ONLINE";
constexpr const char* kSelectionBluetooth = "BLUETOOTH";
constexpr const char* kSelectionAux1 = "AUX1";
constexpr const char* kSelectionAux2 = "AUX2";
constexpr const char* kSelectionAux3 = "AUX3";

constexpr const char* kOtaOwner = "lcir";
constexpr const char* kOtaRepo = "bose-soundtouch-remote-control";

// Friendly name advertised to the network (DHCP hostname + mDNS .local).
constexpr const char* kDeviceHostname = "Bose-SoundTouch-Remote";
}  // namespace

class BoseRemoteApp {
 public:
  void setup() {
    Serial.begin(115200);
    delay(200);

    _inputs.begin();
    initPowerLed();
    _ui.begin(false);
    _ota.begin(FIRMWARE_VERSION, kOtaOwner, kOtaRepo, OTA_ASSET);

    const bool forceSetup = _inputs.powerHeldDuringBoot(BOOT_SERVICE_HOLD_MS);
    if (!forceSetup && _configStore.load(_config)) {
      _ui.begin(_config.displayFlip);
      beginStationMode();
      return;
    }

    startSetupMode(forceSetup ? "Service button held" : "Missing config");
  }

  void loop() {
    _inputs.update();

    if (_setupMode) {
      handleSetupLoop();
      return;
    }

    handleConnectivity();
    _bose.loop();
    _controlWeb.loop();
    if (_controlWeb.consumeOtaApplyRequest()) {
      runOtaUpdate();
    }
    handleInputs();
    flushPendingVolume();
    updatePowerLed();
    renderNormalUi();
  }

 private:
  enum class MenuMode : uint8_t {
    Idle,
    Main,
    VolumeEdit,
    SourceSelect,
    PowerSelect,
    UpdateConfirm,
  };

  struct SourceMenuOption {
    const char* selectionId;
    const char* label;
  };

  static constexpr SourceMenuOption kSourceMenuOptions[5] = {
      {kSelectionOnline, "Online"},
      {kSelectionBluetooth, "Bluetooth"},
      {kSelectionAux1, "Aux1"},
      {kSelectionAux2, "Aux2"},
      {kSelectionAux3, "Aux3"},
  };

  static UiMenuItem makeMenuItem(const String& label, bool enabled) {
    UiMenuItem item;
    item.label = label;
    item.enabled = enabled;
    return item;
  }

  void initPowerLed() {
    pinMode(PIN_LED_STATUS, OUTPUT);
    writeStatusLed(false);
  }

  void writeStatusLed(bool on) {
    const uint8_t level = STATUS_LED_ACTIVE_HIGH ? (on ? HIGH : LOW) : (on ? LOW : HIGH);
    digitalWrite(PIN_LED_STATUS, level);
  }

  void updatePowerLed() {
    const BoseState& state = _bose.state();
    const bool powerOn = state.connected && state.poweredOn;
    writeStatusLed(powerOn);
  }

  void runOtaUpdate() {
    // Blocking: downloads + flashes, then reboots on success. We render progress
    // straight to the OLED since the main loop is paused for the duration.
    _bose.disconnect();
    _ui.renderUpdate("Updating", 0, "Downloading...");

    const bool ok = _ota.applyUpdate([this](int percent) {
      _ui.renderUpdate("Updating", percent, "Do not power off");
    });

    // Only reached on failure (success reboots inside applyUpdate()).
    if (!ok) {
      _ui.renderUpdate("Update failed", 0, _ota.status().lastError);
      showOverlay("Update failed", kSourceOverlayMs);
      delay(3000);
      _lastWifiConnected = false;  // Force reconnect/refresh on next loop.
    }
  }

  void startSetupMode(const String& reason) {
    _setupMode = true;
    _menuMode = MenuMode::Idle;
    _bose.disconnect();
    _controlWeb.stop();
    WiFi.disconnect(true, true);
    writeStatusLed(false);

    const uint64_t chipId = ESP.getEfuseMac();
    const String apName = "BoseRemote-" + String(static_cast<uint16_t>(chipId & 0xFFFF), HEX);
    _portal.start(apName);
    showOverlay(reason, kSourceOverlayMs);
  }

  void beginStationMode() {
    _setupMode = false;
    _menuMode = MenuMode::Idle;
    _portal.stop();
    _controlWeb.stop();
    _lastWifiConnected = false;
    _lastWiFiAttemptMs = 0;
    _lastBoseAttemptMs = 0;
    attemptWiFi();
  }

  void attemptWiFi() {
    if (!_config.isValid()) {
      return;
    }

    // Advertise a friendly DHCP hostname instead of the default "espress_xxxx".
    // Set it on BOTH sides of mode() on purpose: arduino-esp32 2.0.x (our pinned
    // core) only honours it after WIFI_STA exists, while 3.x requires it before
    // mode(). Calling twice is harmless and keeps the hostname working if the
    // platform is ever bumped to 7.x. Must precede begin() so it lands in DHCP.
    WiFi.setHostname(kDeviceHostname);
    WiFi.mode(WIFI_STA);
    WiFi.persistent(false);
    WiFi.setAutoReconnect(true);
    WiFi.setHostname(kDeviceHostname);
    WiFi.begin(_config.wifiSsid.c_str(), _config.wifiPassword.c_str());
    _lastWiFiAttemptMs = millis();
  }

  void handleSetupLoop() {
    _portal.loop();

    DeviceConfig newConfig;
    if (_portal.consumeSavedConfig(newConfig)) {
      _config = newConfig;
      _configStore.save(_config);
      _ui.begin(_config.displayFlip);
      beginStationMode();
      return;
    }

    renderSetupUi();
  }

  void startMdns() {
    // Makes the device reachable as http://Bose-SoundTouch-Remote.local
    MDNS.end();
    if (MDNS.begin(kDeviceHostname)) {
      MDNS.addService("http", "tcp", 80);
    }
  }

  void handleConnectivity() {
    const bool wifiConnected = WiFi.status() == WL_CONNECTED;

    if (wifiConnected && !_lastWifiConnected) {
      _lastWifiConnected = true;
      startMdns();
      _controlWeb.start(_config);
      _lastBoseAttemptMs = millis();
      _bose.connect(_config);
    } else if (!wifiConnected && _lastWifiConnected) {
      _lastWifiConnected = false;
      MDNS.end();
      _controlWeb.stop();
      _bose.disconnect();
    }

    if (!wifiConnected && millis() - _lastWiFiAttemptMs >= kWifiRetryMs) {
      attemptWiFi();
    }

    if (wifiConnected && !_bose.state().connected && millis() - _lastBoseAttemptMs >= kBoseRetryMs) {
      _lastBoseAttemptMs = millis();
      _bose.connect(_config);
    }
  }

  void handleInputs() {
    if (_menuMode != MenuMode::Idle && millis() - _lastMenuInteractionMs >= kMenuTimeoutMs) {
      closeMenu();
    }

    const int delta = _inputs.readEncoderDelta();
    if (delta != 0) {
      handleEncoderDelta(delta);
    }

    if (_inputs.consumeEncoderPressed()) {
      handleEncoderPress();
    }
  }

  void handleEncoderDelta(int delta) {
    noteMenuInteraction();

    switch (_menuMode) {
      case MenuMode::Idle:
        adjustPendingVolume(delta, true);
        break;
      case MenuMode::Main:
        updateMenuSelection(_mainMenuIndex, delta, 4);
        break;
      case MenuMode::VolumeEdit:
        adjustPendingVolume(delta, false);
        break;
      case MenuMode::SourceSelect:
        updateMenuSelection(_sourceMenuIndex, delta, static_cast<int>(sourceMenuItems().size()));
        break;
      case MenuMode::PowerSelect:
        updateMenuSelection(_powerMenuIndex, delta, static_cast<int>(powerMenuItems().size()));
        break;
      case MenuMode::UpdateConfirm:
        if (delta != 0) {
          _updateInstallSelected = !_updateInstallSelected;
        }
        break;
    }
  }

  void handleEncoderPress() {
    noteMenuInteraction();

    switch (_menuMode) {
      case MenuMode::Idle:
        openMainMenu();
        break;
      case MenuMode::Main:
        if (_mainMenuIndex == 0) {
          enterVolumeMenu();
        } else if (_mainMenuIndex == 1) {
          enterSourceMenu();
        } else if (_mainMenuIndex == 2) {
          enterPowerMenu();
        } else {
          enterUpdateFlow();
        }
        break;
      case MenuMode::VolumeEdit:
        commitPendingVolumeNow();
        showOverlay("Vol " + String(displayVolume()), kActionOverlayMs);
        closeMenu();
        break;
      case MenuMode::SourceSelect:
        applySelectedSource();
        break;
      case MenuMode::PowerSelect:
        applySelectedPower();
        break;
      case MenuMode::UpdateConfirm:
        if (_updateInstallSelected) {
          closeMenu();
          runOtaUpdate();
        } else {
          closeMenu();
        }
        break;
    }
  }

  void adjustPendingVolume(int delta, bool showLiveOverlay) {
    const int base = _targetVolume >= 0 ? _targetVolume : _bose.state().volume;
    const int next = constrain(base + delta, 0, 100);
    if (next == base) {
      return;
    }

    _targetVolume = next;
    _lastVolumeChangeMs = millis();
    if (showLiveOverlay) {
      showOverlay("Vol " + String(_targetVolume), kActionOverlayMs);
    }
  }

  void flushPendingVolume() {
    if (_targetVolume < 0) {
      return;
    }

    if (millis() - _lastVolumeChangeMs < kVolumeCommitDelayMs) {
      return;
    }

    commitPendingVolumeNow();
  }

  void commitPendingVolumeNow() {
    if (_targetVolume < 0) {
      return;
    }

    const bool applyMuteState = _bose.state().muted && _targetVolume > 0;
    _bose.setVolume(static_cast<uint8_t>(_targetVolume), applyMuteState, false);
    _targetVolume = -1;
  }

  void openMainMenu() {
    resetMenuAnimation();
    _mainMenuIndex = 0;
    _menuMode = MenuMode::Main;
    noteMenuInteraction();
  }

  void enterVolumeMenu() {
    if (_targetVolume < 0) {
      _targetVolume = _bose.state().volume;
    }
    resetMenuAnimation();
    _menuMode = MenuMode::VolumeEdit;
    noteMenuInteraction();
  }

  void enterSourceMenu() {
    resetMenuAnimation();
    _sourceMenuIndex = currentSourceMenuIndex();
    _menuMode = MenuMode::SourceSelect;
    noteMenuInteraction();
  }

  void enterPowerMenu() {
    resetMenuAnimation();
    _powerMenuIndex = _bose.state().poweredOn ? 1 : 0;
    _menuMode = MenuMode::PowerSelect;
    noteMenuInteraction();
  }

  void enterUpdateFlow() {
    if (WiFi.status() != WL_CONNECTED) {
      showOverlay("No WiFi", kActionOverlayMs);
      closeMenu();
      return;
    }

    // Blocking network check; show a holding screen first since the main loop
    // is paused for the duration.
    _ui.renderBusy("Checking update", "Contacting GitHub");
    _ota.checkForUpdate();

    if (_ota.status().updateAvailable) {
      _updateInstallSelected = false;  // Default to the safe (Cancel) option.
      resetMenuAnimation();
      _menuMode = MenuMode::UpdateConfirm;
      noteMenuInteraction();
      return;
    }

    const String err = _ota.status().lastError;
    showOverlay(err.isEmpty() ? "Up to date" : "OTA: " + err, kSourceOverlayMs);
    closeMenu();
  }

  void closeMenu() {
    _menuMode = MenuMode::Idle;
    _mainMenuIndex = 0;
    _sourceMenuIndex = 0;
    _powerMenuIndex = 0;
    _lastMenuInteractionMs = 0;
    resetMenuAnimation();
  }

  void applySelectedSource() {
    const auto items = sourceMenuItems();
    if (_sourceMenuIndex < 0 || _sourceMenuIndex >= static_cast<int>(items.size()) ||
        !items[_sourceMenuIndex].enabled) {
      showOverlay("Source unavailable", kActionOverlayMs);
      closeMenu();
      return;
    }

    const String sourceId = kSourceMenuOptions[_sourceMenuIndex].selectionId;
    const String label = kSourceMenuOptions[_sourceMenuIndex].label;
    if (_bose.selectSource(sourceId)) {
      showOverlay(label, kSourceOverlayMs);
    } else {
      showOverlay("Source failed", kActionOverlayMs);
    }
    closeMenu();
  }

  void applySelectedPower() {
    const auto items = powerMenuItems();
    if (_powerMenuIndex < 0 || _powerMenuIndex >= static_cast<int>(items.size()) ||
        !items[_powerMenuIndex].enabled) {
      showOverlay("Power unchanged", kActionOverlayMs);
      closeMenu();
      return;
    }

    bool ok = false;
    String label;
    if (_powerMenuIndex == 0) {
      ok = _bose.wake();
      label = "Power On";
    } else {
      ok = _bose.standby();
      label = "Standby";
    }

    showOverlay(ok ? label : "Power failed", kActionOverlayMs);
    closeMenu();
  }

  int displayVolume() const {
    return _targetVolume >= 0 ? _targetVolume : _bose.state().volume;
  }

  int currentSourceMenuIndex() const {
    const String currentId = _bose.currentSelectionId();
    for (int i = 0; i < 5; ++i) {
      if (currentId.equalsIgnoreCase(kSourceMenuOptions[i].selectionId)) {
        return i;
      }
    }
    return 0;
  }

  std::vector<UiMenuItem> sourceMenuItems() const {
    std::vector<UiMenuItem> items;
    items.reserve(5);

    for (const auto& option : kSourceMenuOptions) {
      items.push_back(makeMenuItem(option.label, isSourceSelectionAvailable(option.selectionId)));
    }
    return items;
  }

  std::vector<UiMenuItem> powerMenuItems() const {
    std::vector<UiMenuItem> items;
    items.reserve(2);
    items.push_back(makeMenuItem("On", !_bose.state().poweredOn));
    items.push_back(makeMenuItem("Off", _bose.state().poweredOn));
    return items;
  }

  bool isSourceSelectionAvailable(const String& selectionId) const {
    return _bose.canSelectSource(selectionId);
  }

  int wrapIndex(int current, int delta, int count) const {
    if (count <= 0) {
      return 0;
    }

    int index = current;
    const int direction = delta >= 0 ? 1 : -1;
    for (int step = 0; step < abs(delta); ++step) {
      index = (index + direction + count) % count;
    }
    return index;
  }

  void updateMenuSelection(int& currentIndex, int delta, int count) {
    if (count <= 0 || delta == 0) {
      return;
    }

    const int previousIndex = wrapIndex(currentIndex, 0, count);
    const int nextIndex = wrapIndex(currentIndex, delta, count);
    if (nextIndex == currentIndex) {
      return;
    }

    _menuPreviousIndex = previousIndex;
    _menuAnimationDirection = delta > 0 ? 1 : -1;
    _menuAnimationActive = true;
    _menuAnimationStartMs = millis();
    currentIndex = nextIndex;
  }

  void updateMenuAnimation() {
    if (!_menuAnimationActive) {
      return;
    }

    if (millis() - _menuAnimationStartMs >= kMenuAnimationMs) {
      resetMenuAnimation();
    }
  }

  void resetMenuAnimation() {
    _menuAnimationActive = false;
    _menuAnimationStartMs = 0;
    _menuAnimationDirection = 0;
    _menuPreviousIndex = 0;
  }

  UiMenuModel currentMenuModel(const String& statusHint) const {
    UiMenuModel menu;

    switch (_menuMode) {
      case MenuMode::Main:
        menu.title = "Menu";
        menu.items.clear();
        menu.items.push_back(makeMenuItem("Volume", true));
        menu.items.push_back(makeMenuItem("Source", true));
        menu.items.push_back(makeMenuItem("Power", true));
        menu.items.push_back(makeMenuItem("Update", true));
        menu.selectedIndex = _mainMenuIndex;
        break;
      case MenuMode::VolumeEdit:
        menu.items.clear();
        menu.items.push_back(makeMenuItem(String(displayVolume()), true));
        menu.selectedIndex = 0;
        break;
      case MenuMode::SourceSelect:
        menu.items = sourceMenuItems();
        menu.selectedIndex = _sourceMenuIndex;
        break;
      case MenuMode::PowerSelect:
        menu.items = powerMenuItems();
        menu.selectedIndex = _powerMenuIndex;
        break;
      case MenuMode::UpdateConfirm:
        // Rendered via renderUpdatePrompt(), not the carousel.
        break;
      case MenuMode::Idle:
        menu.title = "";
        menu.detail = statusHint;
        break;
    }

    menu.previousSelectedIndex = _menuAnimationActive ? _menuPreviousIndex : menu.selectedIndex;
    menu.transitionActive = _menuAnimationActive;
    menu.transitionDirection = _menuAnimationDirection;
    if (_menuAnimationActive) {
      const unsigned long elapsed = millis() - _menuAnimationStartMs;
      const unsigned long clamped = min(elapsed, kMenuAnimationMs);
      menu.transitionProgress = static_cast<uint8_t>((clamped * 255U) / kMenuAnimationMs);
    } else {
      menu.transitionProgress = 255;
    }

    return menu;
  }

  void renderSetupUi() {
    static unsigned long lastRenderMs = 0;
    if (millis() - lastRenderMs < kUiRefreshMs) {
      return;
    }
    lastRenderMs = millis();

    _ui.renderSetup(_portal.apName(), WiFi.softAPIP().toString(), "Join AP and save config");
  }

  void renderNormalUi() {
    static unsigned long lastRenderMs = 0;
    if (millis() - lastRenderMs < kUiRefreshMs) {
      return;
    }
    lastRenderMs = millis();

    BoseState view = _bose.state();
    if (_targetVolume >= 0) {
      view.volume = static_cast<uint8_t>(_targetVolume);
      if (_targetVolume > 0) {
        view.muted = false;
      }
    }

    const bool wifiConnected = WiFi.status() == WL_CONNECTED;
    String statusHint;
    if (!wifiConnected) {
      statusHint = "Waiting for WiFi";
    } else if (!view.connected) {
      statusHint = "Waiting for Bose host";
    } else if (!view.wsConnected) {
      statusHint = "Polling fallback active";
    }

    if (_menuMode == MenuMode::UpdateConfirm) {
      _ui.renderUpdatePrompt(_ota.status().latestVersion, _updateInstallSelected);
      return;
    }

    if (_menuMode != MenuMode::Idle) {
      updateMenuAnimation();
      _ui.renderMenu(view, wifiConnected, currentMenuModel(statusHint), statusHint);
      return;
    }

    const String overlay = millis() < _overlayUntilMs ? _overlayText : "";
    _ui.renderNormal(view, wifiConnected, overlay, statusHint);
  }

  void showOverlay(const String& text, unsigned long durationMs) {
    _overlayText = text;
    _overlayUntilMs = millis() + durationMs;
  }

  void noteMenuInteraction() {
    if (_menuMode != MenuMode::Idle) {
      _lastMenuInteractionMs = millis();
    }
  }

  ConfigStore _configStore;
  DeviceConfig _config;
  InputController _inputs;
  UiRenderer _ui;
  BoseClient _bose;
  OtaUpdater _ota;
  ControlWebServer _controlWeb{_bose, _ota};
  CaptivePortal _portal;

  bool _setupMode = false;
  bool _lastWifiConnected = false;
  unsigned long _lastWiFiAttemptMs = 0;
  unsigned long _lastBoseAttemptMs = 0;
  int _targetVolume = -1;
  unsigned long _lastVolumeChangeMs = 0;
  String _overlayText;
  unsigned long _overlayUntilMs = 0;

  MenuMode _menuMode = MenuMode::Idle;
  int _mainMenuIndex = 0;
  int _sourceMenuIndex = 0;
  int _powerMenuIndex = 0;
  bool _updateInstallSelected = false;
  unsigned long _lastMenuInteractionMs = 0;
  bool _menuAnimationActive = false;
  int _menuPreviousIndex = 0;
  int8_t _menuAnimationDirection = 0;
  unsigned long _menuAnimationStartMs = 0;
};

constexpr BoseRemoteApp::SourceMenuOption BoseRemoteApp::kSourceMenuOptions[5];

BoseRemoteApp app;

void setup() {
  app.setup();
}

void loop() {
  app.loop();
}

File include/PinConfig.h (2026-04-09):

#pragma once

#include <stdint.h>

// Default prototype wiring for LOLIN/Wemos S2 Mini.
// The OLED is a generic 0.96" 128x64 I2C SSD1306-compatible module.
constexpr int PIN_I2C_SDA = 33;
constexpr int PIN_I2C_SCL = 35;
constexpr uint8_t DISPLAY_I2C_ADDRESS = 0x3C;
constexpr uint32_t DISPLAY_I2C_CLOCK_HZ = 400000;

constexpr int PIN_ENCODER_A = 7;
constexpr int PIN_ENCODER_B = 9;
constexpr int PIN_ENCODER_BUTTON = 11;

constexpr int PIN_BUTTON_SOURCE = 5;
constexpr int PIN_LED_STATUS = 18;
constexpr bool STATUS_LED_ACTIVE_HIGH = true;

constexpr unsigned long BOOT_SERVICE_HOLD_MS = 1500;
constexpr unsigned long BUTTON_DEBOUNCE_MS = 25;

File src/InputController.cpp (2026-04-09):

#include <stdlib.h>

#include "InputController.h"

namespace {
constexpr int kEncoderCountsPerStep = 2;
}

void InputController::begin() {
  initButton(_encoderButton, PIN_ENCODER_BUTTON);

  ESP32Encoder::useInternalWeakPullResistors = puType::up;
  _encoder.attachHalfQuad(PIN_ENCODER_A, PIN_ENCODER_B);
  _encoder.setCount(0);
  _lastEncoderCount = 0;
}

void InputController::update() {
  updateButton(_encoderButton);
}

bool InputController::powerHeldDuringBoot(unsigned long durationMs) const {
  const unsigned long started = millis();
  while (millis() - started < durationMs) {
    if (digitalRead(PIN_ENCODER_BUTTON) != LOW) {
      return false;
    }
    delay(10);
  }
  return true;
}

bool InputController::consumeEncoderPressed() {
  return consumeButton(_encoderButton);
}

int InputController::readEncoderDelta() {
  const int64_t current = _encoder.getCount();
  const int delta = static_cast<int>(current - _lastEncoderCount);
  _lastEncoderCount = current;

  _pendingEncoderCounts += delta;
  if (abs(_pendingEncoderCounts) < kEncoderCountsPerStep) {
    return 0;
  }

  const int steps = _pendingEncoderCounts / kEncoderCountsPerStep;
  _pendingEncoderCounts %= kEncoderCountsPerStep;
  return steps;
}

void InputController::initButton(ButtonState& button, int pin) {
  button.pin = pin;
  pinMode(pin, INPUT_PULLUP);
  button.stableLevel = digitalRead(pin);
  button.lastReading = button.stableLevel;
  button.lastChangeMs = millis();
}

void InputController::updateButton(ButtonState& button) {
  const bool reading = digitalRead(button.pin);
  if (reading != button.lastReading) {
    button.lastReading = reading;
    button.lastChangeMs = millis();
  }

  if ((millis() - button.lastChangeMs) < BUTTON_DEBOUNCE_MS) {
    return;
  }

  if (reading != button.stableLevel) {
    button.stableLevel = reading;
    if (button.stableLevel == LOW) {
      button.pressedEvent = true;
    }
  }
}

bool InputController::consumeButton(ButtonState& button) {
  if (!button.pressedEvent) {
    return false;
  }

  button.pressedEvent = false;
  return true;
}

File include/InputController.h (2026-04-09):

#pragma once

#include <Arduino.h>
#include <ESP32Encoder.h>

#include "PinConfig.h"

class InputController {
 public:
  void begin();
  void update();

  bool powerHeldDuringBoot(unsigned long durationMs) const;
  bool consumeEncoderPressed();
  int readEncoderDelta();

 private:
  struct ButtonState {
    int pin = -1;
    bool stableLevel = HIGH;
    bool lastReading = HIGH;
    bool pressedEvent = false;
    unsigned long lastChangeMs = 0;
  };

  void initButton(ButtonState& button, int pin);
  void updateButton(ButtonState& button);
  bool consumeButton(ButtonState& button);

  ButtonState _encoderButton;
  ESP32Encoder _encoder;
  int64_t _lastEncoderCount = 0;
  int _pendingEncoderCounts = 0;
};

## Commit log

2026-04-09 Add wiring diagram, project pinout assets, and CLAUDE.md
    - Add SVG project wiring diagram and base PNG pinout for LOLIN/Wemos S2 Mini
    - Update wiring docs (CZ + EN) with diagram reference, clearer LED resistor wiring, and block diagram fixes
    - Add CLAUDE.md with project overview and architecture guidance
2026-04-09 Add encoder menu control and simplify status LED
2026-04-09 Improved docs
    [bose_remote_enclosure.scad]
2026-06-13 Add OTA self-update from GitHub Releases
    Pull-based firmware updates triggered from the LAN web UI: the device
    queries the GitHub API for the latest release, compares its tag against
    the build-time FIRMWARE_VERSION, and downloads/flashes the per-board
    firmware-<env>.bin asset via the ESP32 OTA mechanism.
    - OtaUpdater module: GitHub API query, semver compare, HTTPUpdate flash
    - Web UI Firmware section + REST: /api/ota, /api/ota/check, /api/ota/apply
    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
2026-06-13 Add update countdown overlay, favicon, and friendly hostname
    - Web UI: circular 30s countdown overlay shown during OTA apply, then
    auto-reloads the page (fixes [hidden] being overridden by display:flex
    via an explicit .overlay[hidden]{display:none} rule)
    - Inline SVG favicon (speaker + sound waves) served from /favicon.svg
    - Advertise on the network as "Bose-SoundTouch-Remote": WiFi.setHostname()
    for DHCP plus mDNS (Bose-SoundTouch-Remote.local, _http._tcp)
    [main.cpp]
2026-06-13 Fix AUX1 selection on OLED and add OTA update to encoder menu
    - AUX1 was unreachable from the OLED source menu: it mapped to selection
    id "AUX" but the amp exposes the source as "AUX1" (sourceAccount). Fixed
    the menu mapping and the wake-preference list in BoseClient.
    - Encoder menu gains an "Update" entry: checks GitHub for a newer release,
    shows an Install/Cancel confirmation with the version, then runs the same
    OTA flow as the web UI.
    - OLED renders the update progress for web-triggered updates too (shared
    runOtaUpdate path), plus new renderUpdatePrompt/renderBusy screens.
    [UiRenderer.cpp, main.cpp]
2026-06-13 Pin espressif32 to 6.x and harden WiFi hostname ordering
    - Pin platform to espressif32@^6.13.0 so builds stay on arduino-esp32
    2.0.x; the jump to 7.x (core 3.x / IDF5) is now a deliberate migration.
    - Call WiFi.setHostname() both before and after WiFi.mode() so the
    friendly DHCP hostname survives a future bump to core 3.x (which
    requires it before mode()), while still working on the pinned 2.0.x.
2026-06-13 Document release/versioning conventions in CLAUDE.md
    Add a "Releases & Conventions" section: release notes are always written
    in English, semantic vX.Y.Z tagging with git-describe versioning, the
    tag-triggered release workflow, the deliberate platform pin, OTA-slot size
    budget, and the device's network name.
2026-08-21 Add compact landscape enclosure
    [compact-landscape-body.stl, compact-landscape-panel-layout.stl, compact-landscape-rear-lid.stl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]
2026-08-21 Refine compact landscape enclosure layout
    [compact-landscape-body.stl, compact-landscape-panel-layout.stl, compact-landscape-rear-lid.stl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]
